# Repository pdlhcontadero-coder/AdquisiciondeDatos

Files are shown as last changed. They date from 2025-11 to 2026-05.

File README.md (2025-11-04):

# ⚙️ Proyecto: Sistema de Monitoreo IoT Aplicado a Cultivos de Lechuga Hidropónica

Este proyecto utiliza la **ESP32** como microcontrolador principal en tres diferentes versiones, con el objetivo de recolectar datos de variables críticas de cultivos hidropónicos, tales como:  
**pH, conductividad eléctrica, temperatura y humedad relativa, temperatura del agua, nivel de agua en los tubos y nivel de agua en el tanque.**

---

<p align="center">
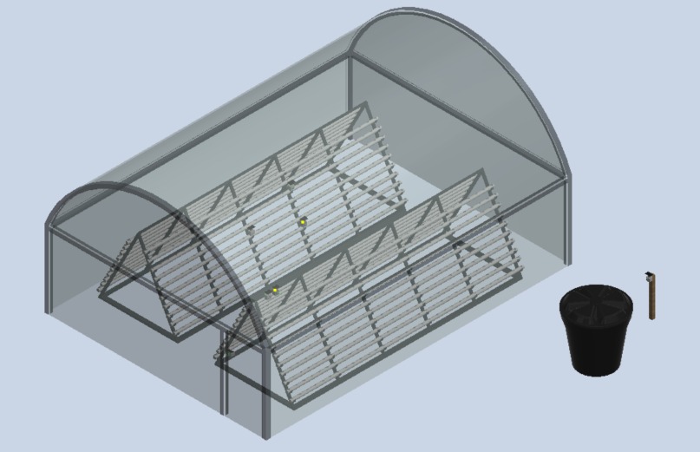
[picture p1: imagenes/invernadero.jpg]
  <br>
  <em>Invernadero - Unidad de Cultivo</em>
</p>

---

## 🧰 Componentes Utilizados

- 1 LilyGo T-SIM-A7670E  
- 3 ESP32-C3 Super Mini Plus  
- 1 ESP32 DevKit V1  
- 1 Sensor de pH con electrodo industrial  
- 1 Sensor de conductividad eléctrica  
- 1 Sensor de temperatura y humedad DHT22  
- 2 Sensores de temperatura DS18B20  
- 4 Sensores de nivel analógicos  
- 1 Sensor de nivel ultrasónico  
- 2 Módulos ADC ADS1115  
- 5 Pantallas OLED 1.3"  
- 5 Módulos de carga TP4056  
- 5 Paneles solares de 5 V  
- 10 Baterías 18650 (2 por cada módulo)  
- 9 Pulsadores (3 por cada módulo que los incluye)  

---

## 🧠 Funcionamiento General

El sistema está conformado por **5 módulos**, de los cuales:
- **4 módulos emisores** se encargan de recolectar los datos de los sensores asignados y enviarlos mediante el protocolo ESPNOW.
- **1 módulo receptor (principal)** recibe toda la información de los emisores y la envía a una **base de datos** para su almacenamiento y análisis.

---

## 🖼️ Diagramas e Imágenes de los Módulos

### 📊 Diagramas de Conexión

<p align="center">
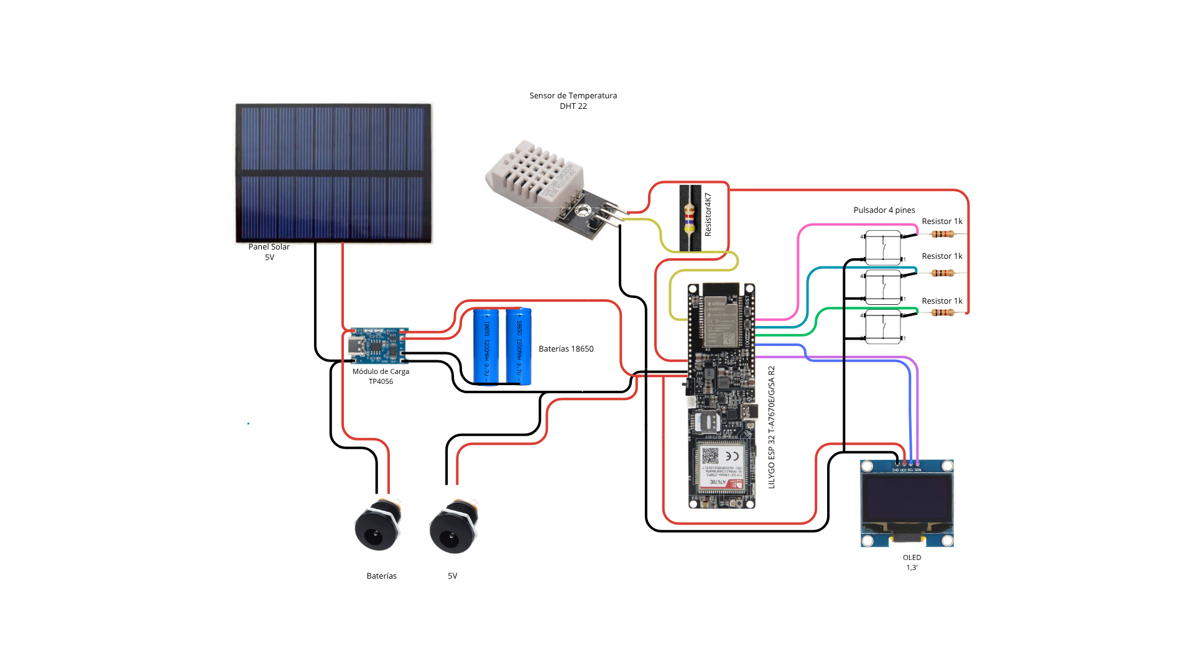
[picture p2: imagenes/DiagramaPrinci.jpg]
  <br>
  <em>Diagrama de conexión - Módulo principal</em>
</p>

<p align="center">
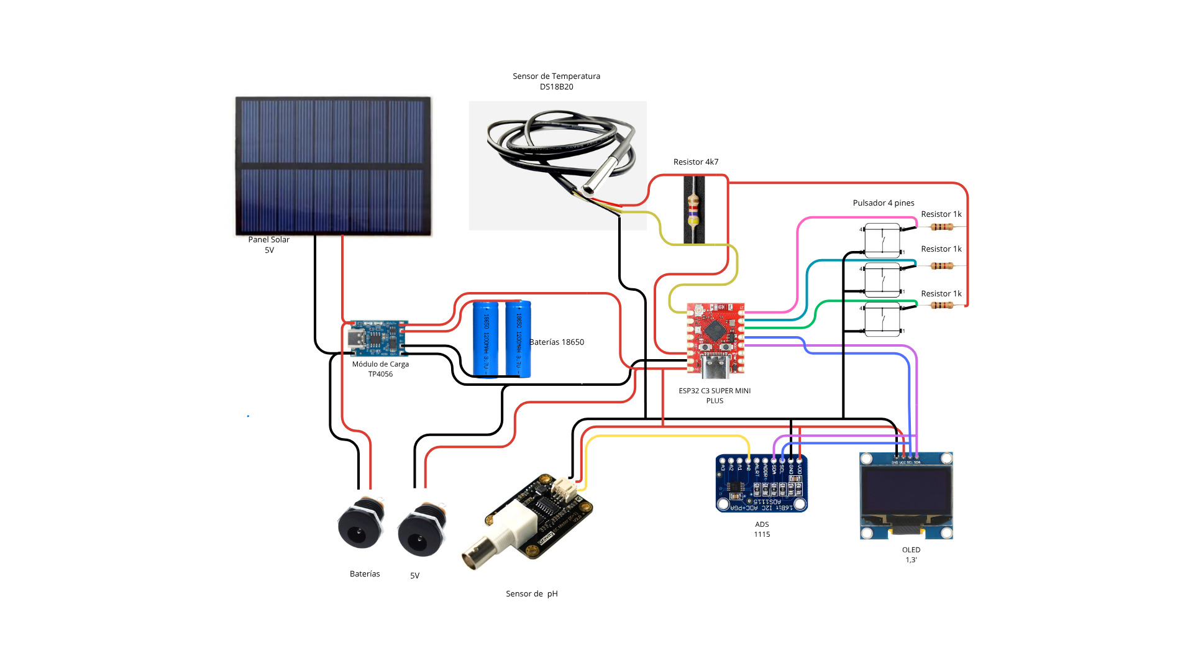
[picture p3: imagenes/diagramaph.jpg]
  <br>
  <em>Diagrama de conexión - Módulo pH</em>
</p>

<p align="center">
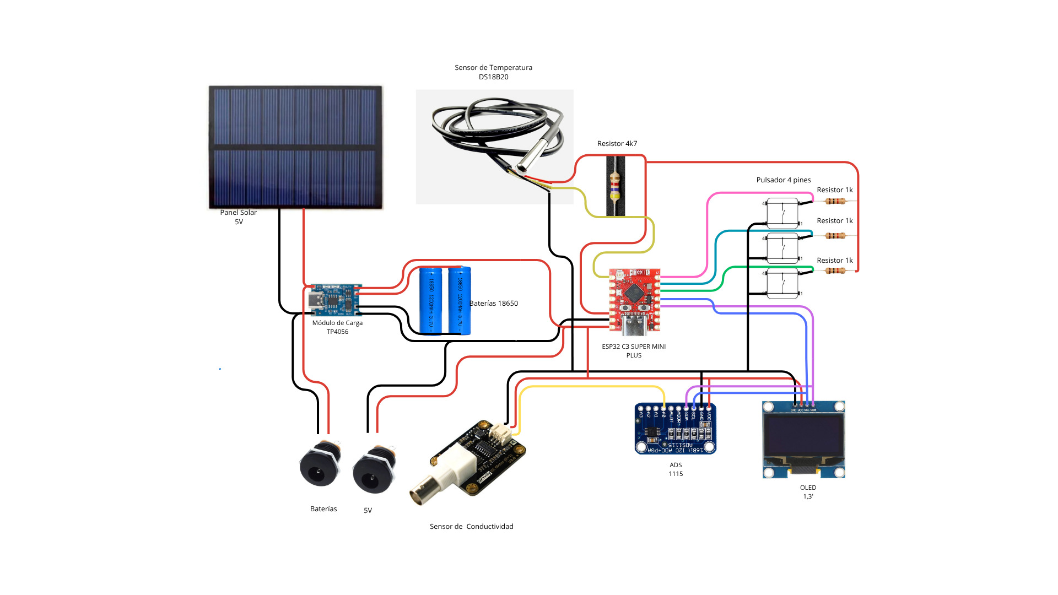
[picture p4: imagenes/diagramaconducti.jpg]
  <br>
  <em>Diagrama de conexión - Módulo conductividad</em>
</p>

<p align="center">
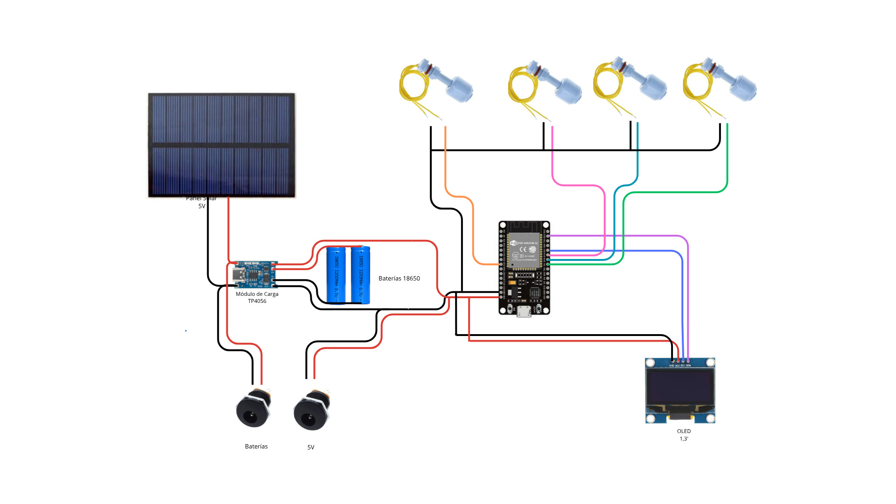
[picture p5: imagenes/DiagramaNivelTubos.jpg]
  <br>
  <em>Diagrama de conexión - Módulo nivel de agua en tubos</em>
</p>

<p align="center">
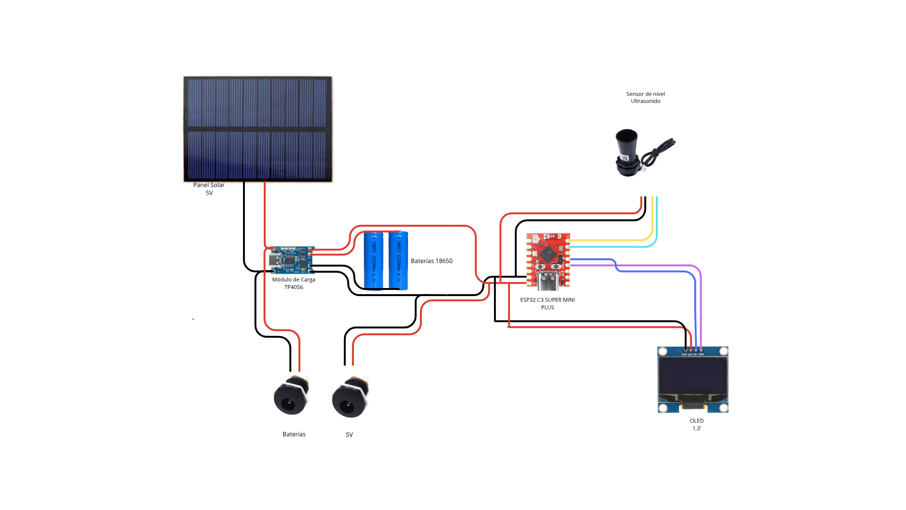
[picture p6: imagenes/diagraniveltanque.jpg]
  <br>
  <em>Diagrama de conexión - Módulo nivel de agua en tanque</em>
</p>

---

### 🧩 Montaje Real de los Módulos

<p align="center">
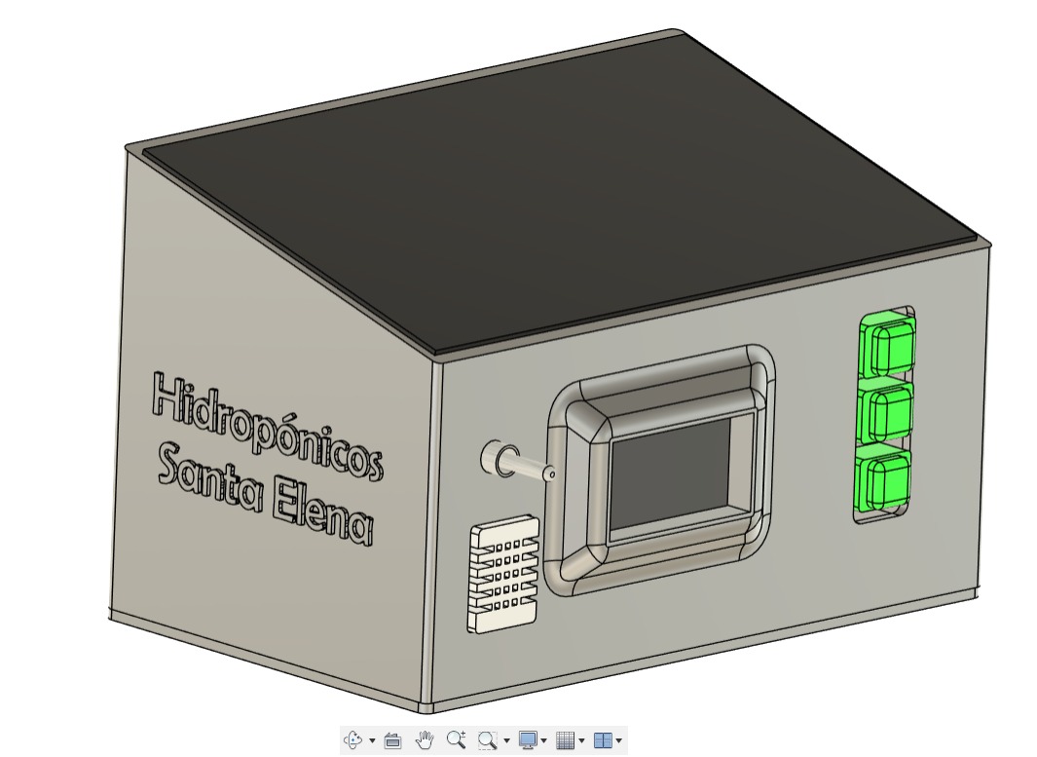
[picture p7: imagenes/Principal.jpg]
  <br>
  <em>Montaje del módulo principal</em>
</p>

<p align="center">
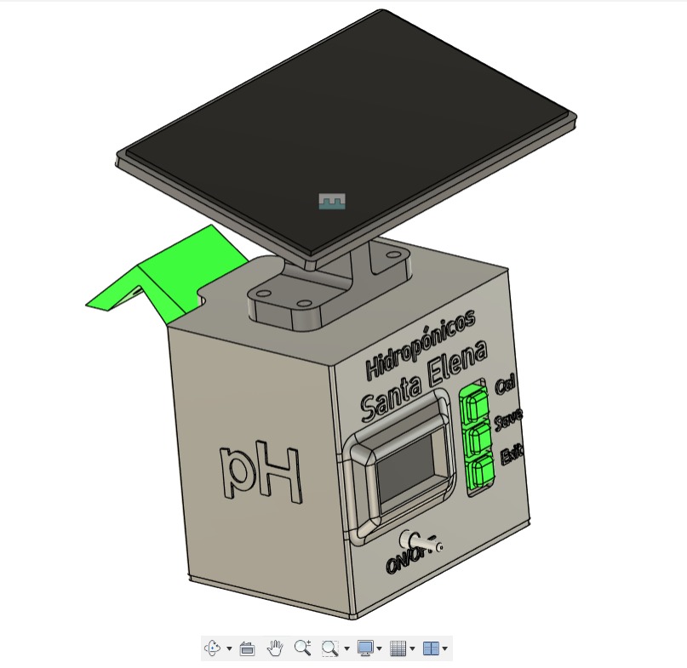
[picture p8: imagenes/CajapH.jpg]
  <br>
  <em>Montaje del módulo pH</em>
</p>

<p align="center">
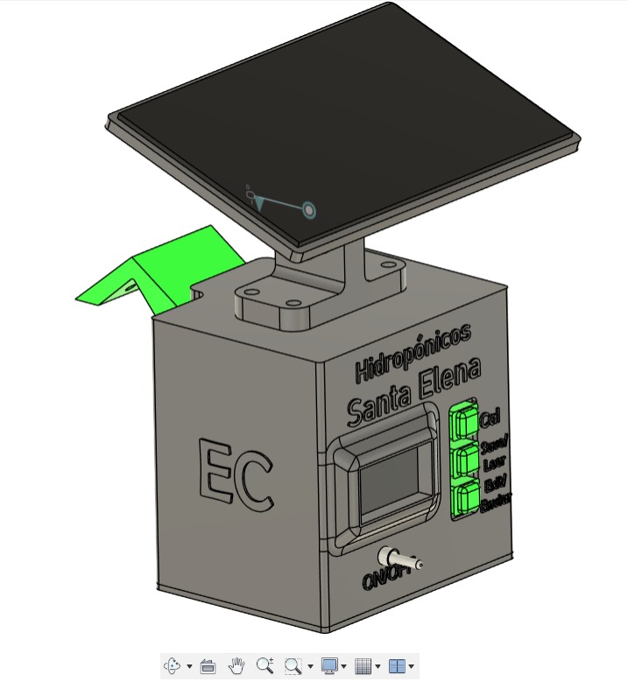
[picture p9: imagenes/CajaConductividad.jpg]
  <br>
  <em>Montaje del módulo conductividad</em>
</p>

<p align="center">
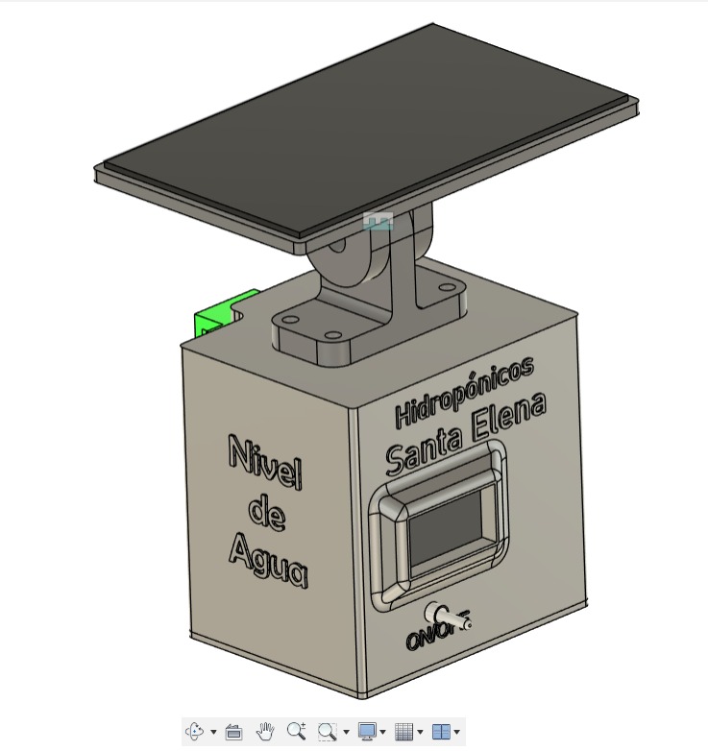
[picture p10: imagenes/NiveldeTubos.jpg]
  <br>
  <em>Montaje del módulo nivel de agua en tubos</em>
</p>

<p align="center">
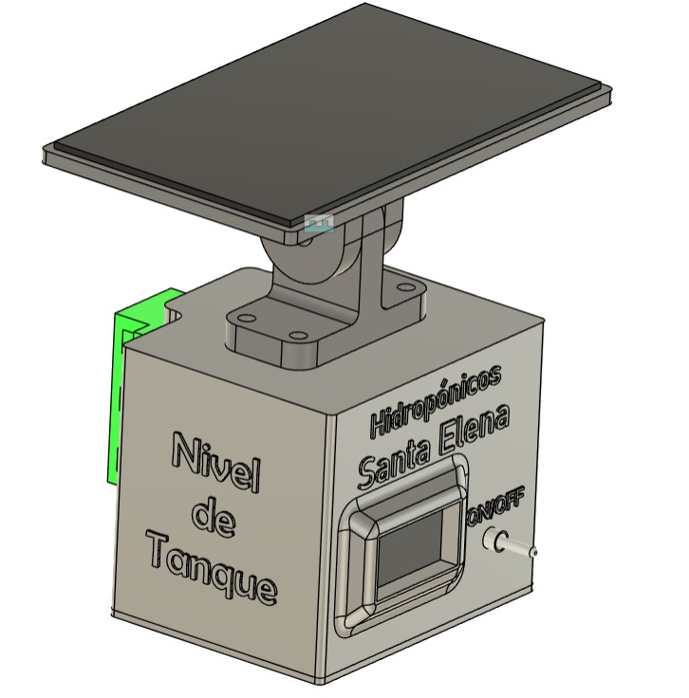
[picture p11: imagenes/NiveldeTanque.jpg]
  <br>
  <em>Montaje del módulo nivel de agua en tanque</em>
</p>

---
###  🔗 Repositorio relacionado

📦 [Repositorio de base de datos y página web](https://github.com/pdlhcontadero-coder/PMLHC)

---
## 👥 Autores

- **Alejandro Díaz Igua**  
- **David Eraso García**  
- **Ana Sofía Muñoz Villota**  
- **Ivette Camila Yepez Morán**

---

📍 *Proyecto académico.*

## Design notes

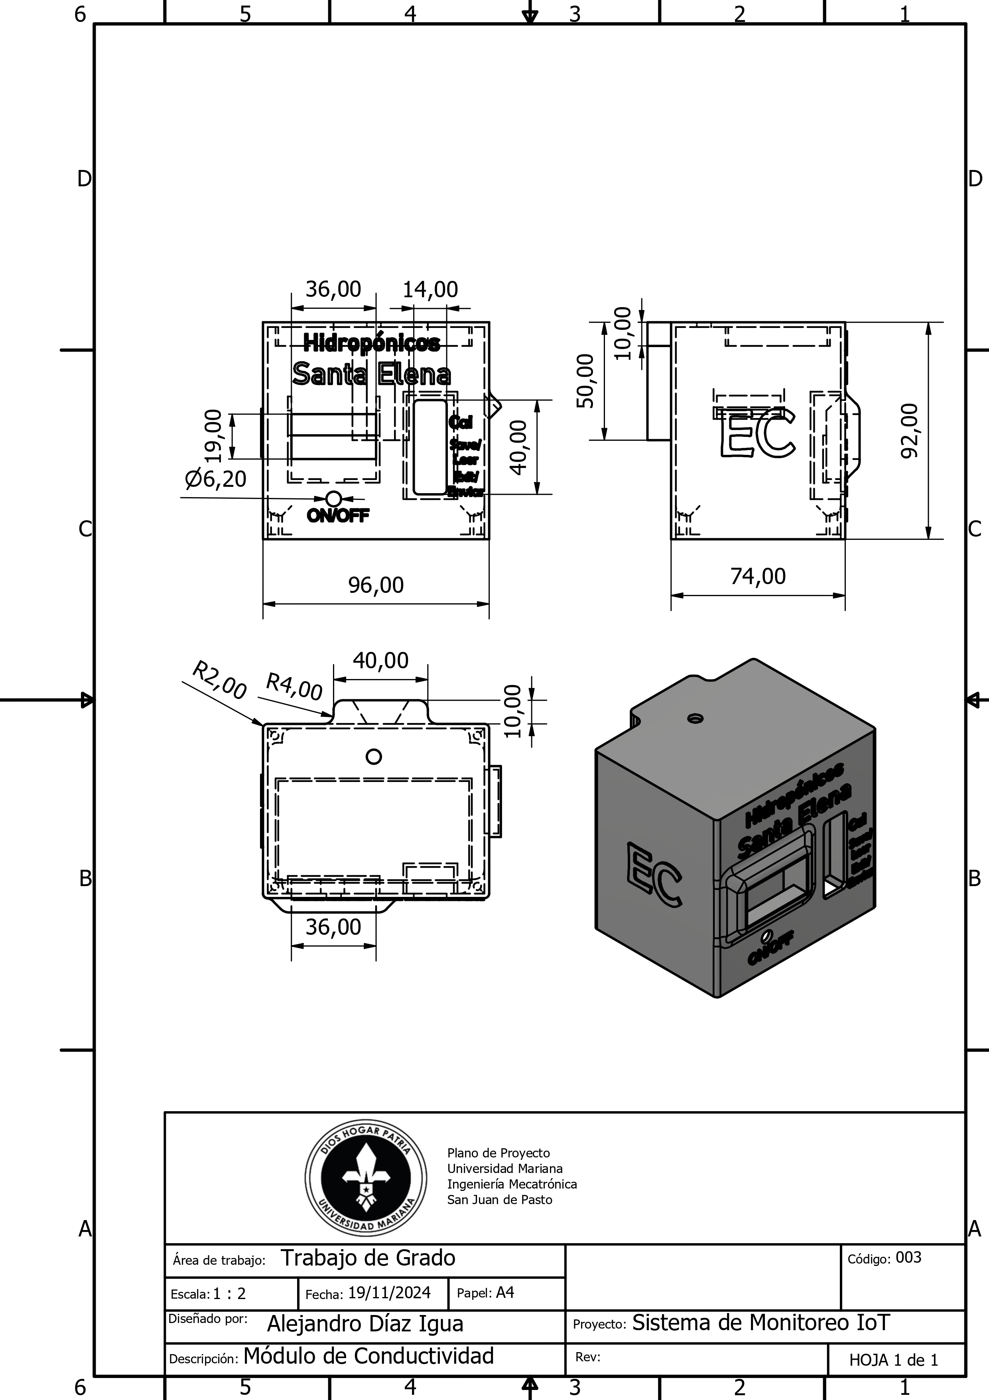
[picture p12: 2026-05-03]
Diseño 3D - Inventor/Planos Finales Sistema de Monitoreo/Planos en imagen/003 Plano 3 - Módulo de Conductividad (Caja).jpg

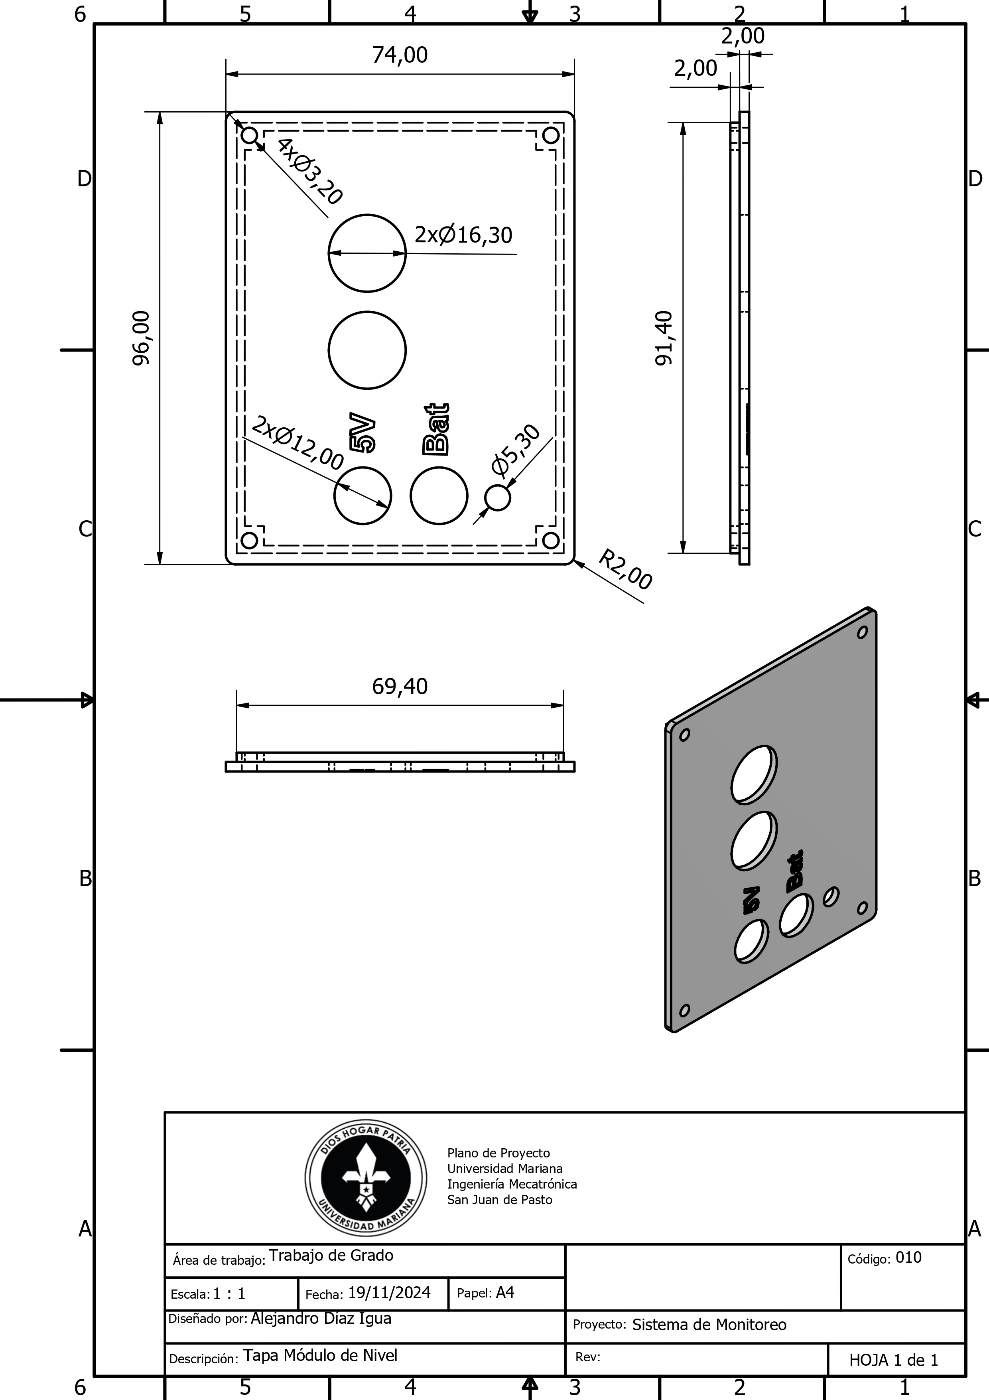
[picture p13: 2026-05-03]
Diseño 3D - Inventor/Planos Finales Sistema de Monitoreo/Planos en imagen/010 Plano 10 - Módulo de Nivel de Agua (Tapa).jpg

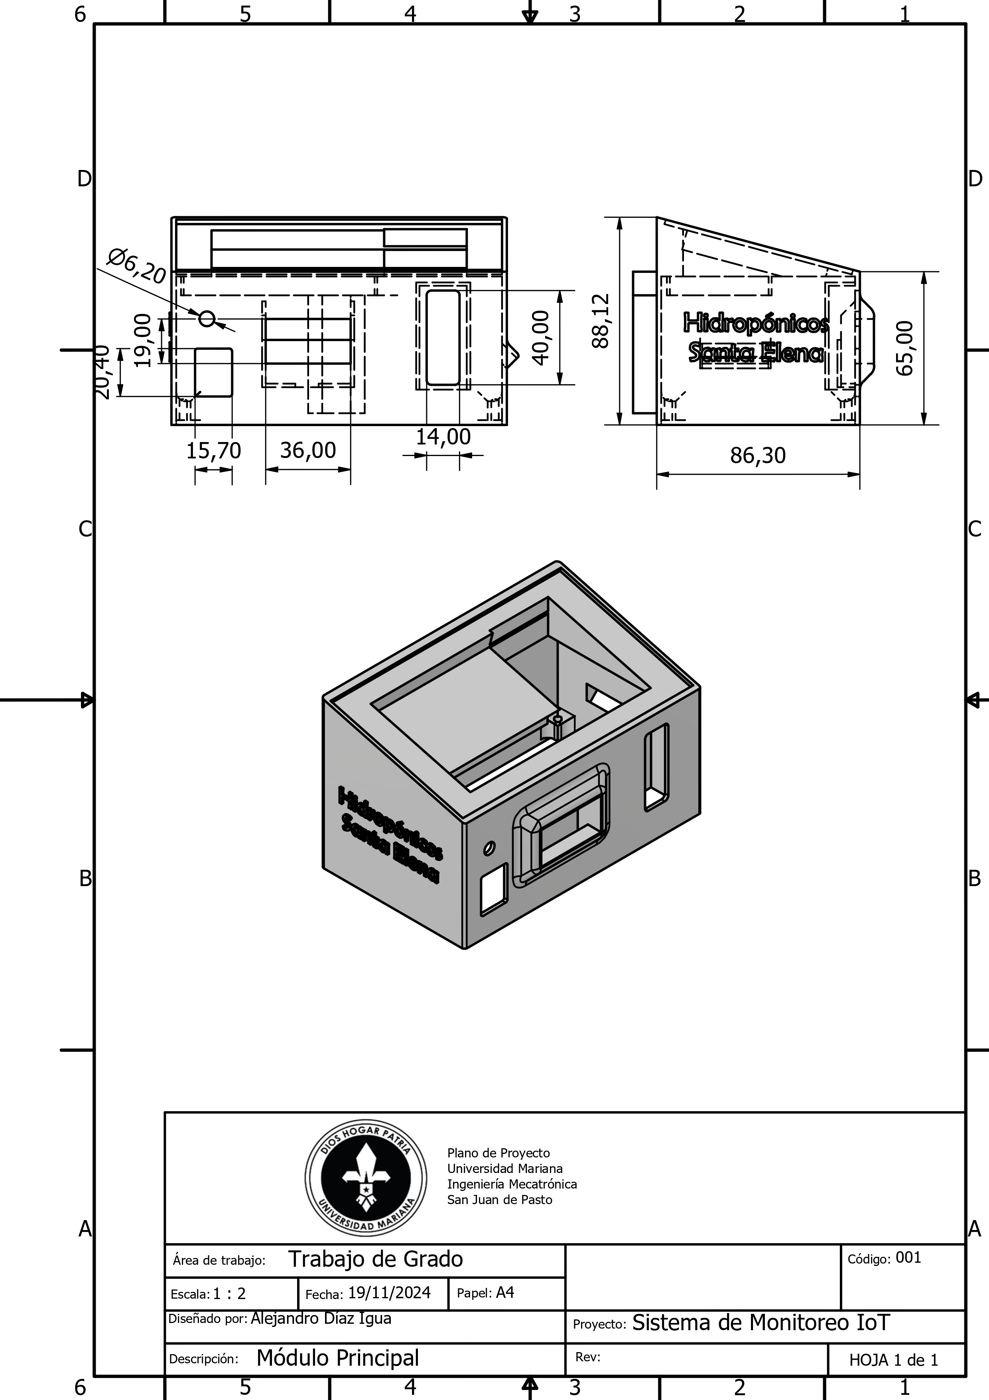
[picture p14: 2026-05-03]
Diseño 3D - Inventor/Planos Finales Sistema de Monitoreo/Planos en imagen/001 Plano 1 - Módulo Principal (Caja).jpg

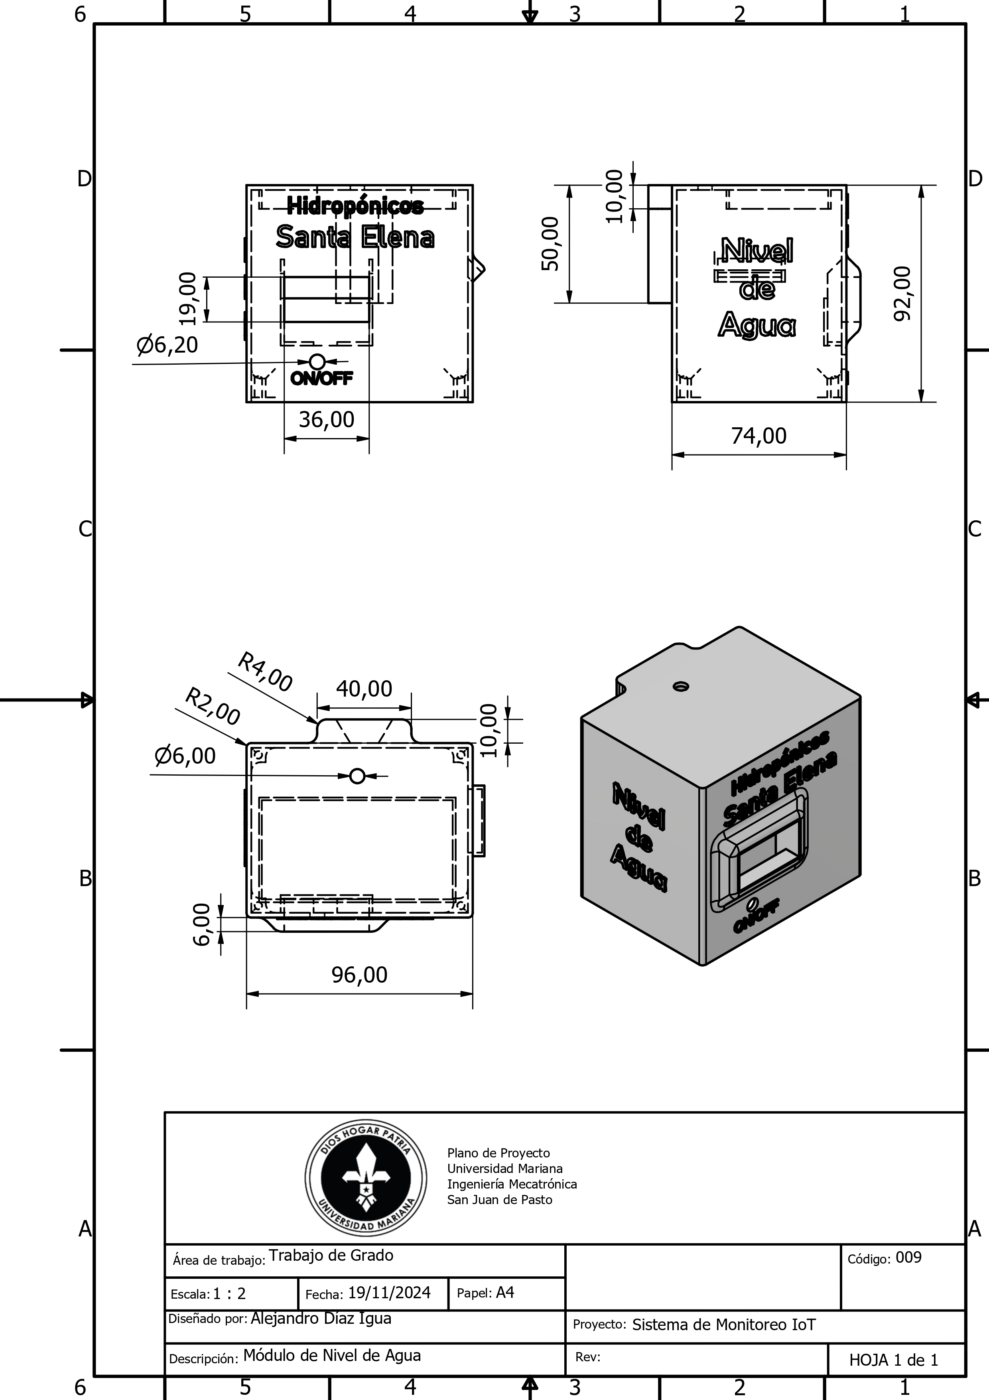
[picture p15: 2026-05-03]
Diseño 3D - Inventor/Planos Finales Sistema de Monitoreo/Planos en imagen/009 Plano 9 - Módulo de Nivel de Agua (Caja).jpg

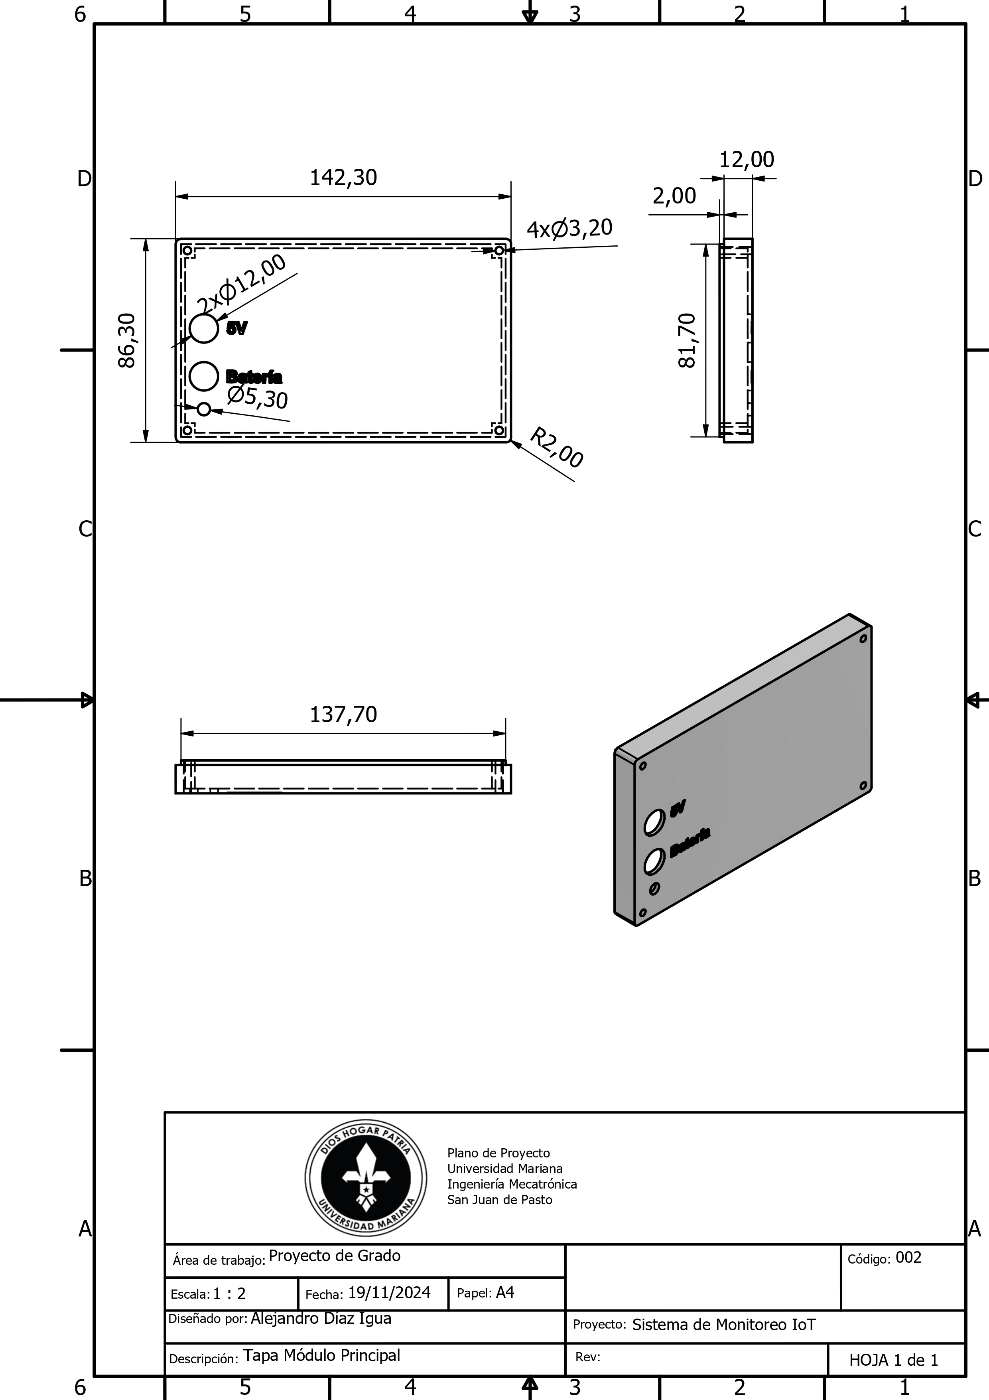
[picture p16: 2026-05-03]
Diseño 3D - Inventor/Planos Finales Sistema de Monitoreo/Planos en imagen/002 Plano 2 - Módulo Principal (Tapa).jpg

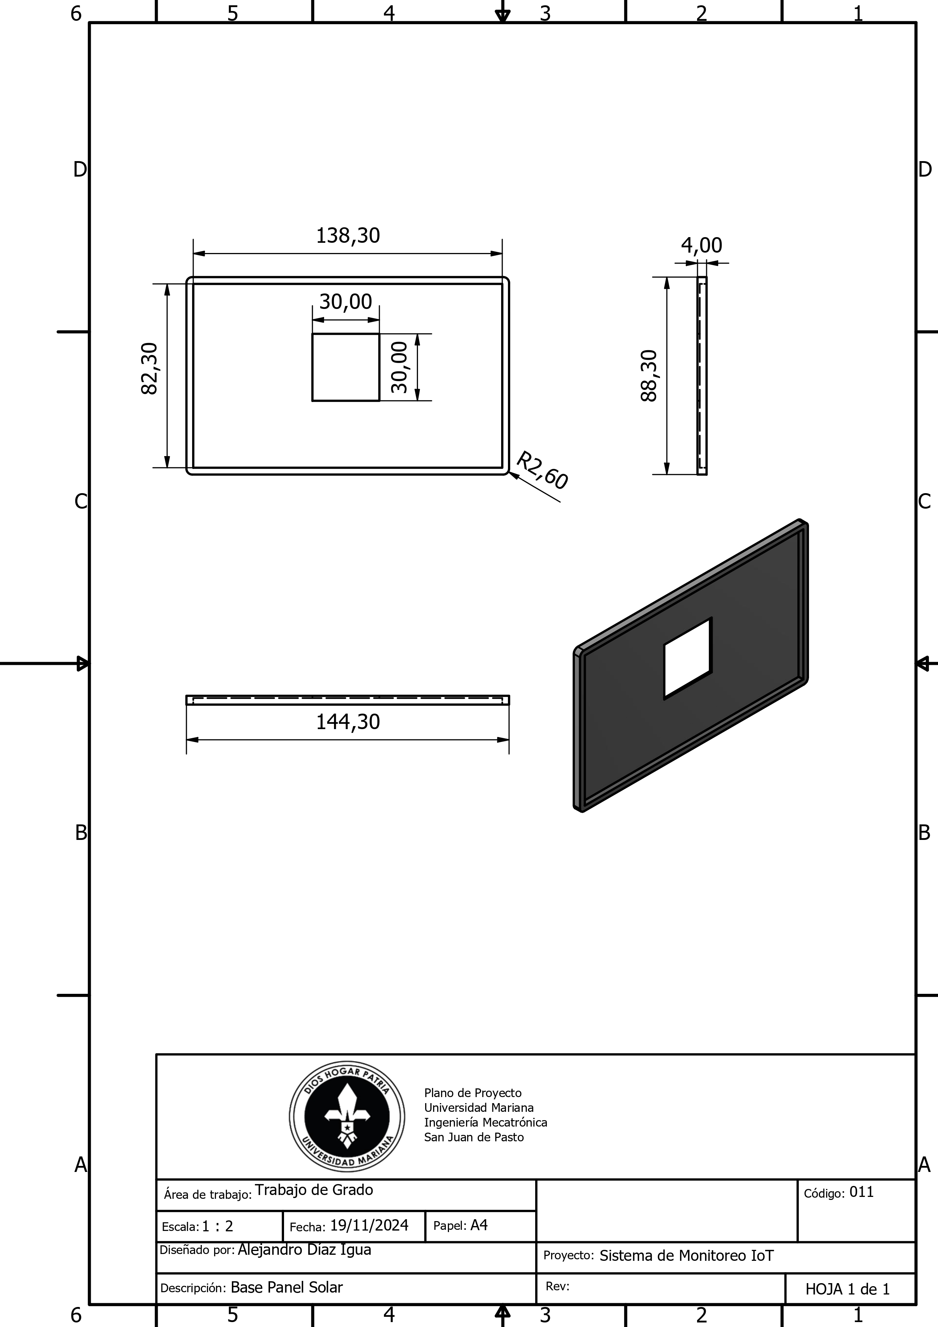
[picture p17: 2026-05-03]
Diseño 3D - Inventor/Planos Finales Sistema de Monitoreo/Planos en imagen/011 Plano 11 - Base Panel Solar.jpg

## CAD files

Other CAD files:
Diseño 3D - Inventor/Invernadero/Ensamble/Ensamblaje1.iam
Diseño 3D - Inventor/Invernadero/Ensamble/OldVersions/Ensamblaje1.0007.iam
Diseño 3D - Inventor/Invernadero/Piezas/Caja.ipt
Diseño 3D - Inventor/Invernadero/Piezas/Invernadero.ipt
Diseño 3D - Inventor/Invernadero/Piezas/OldVersions/Invernadero.0002.ipt
Diseño 3D - Inventor/Invernadero/Piezas/OldVersions/TapaTanque.0001.ipt
Diseño 3D - Inventor/Invernadero/Piezas/OldVersions/Torre.0004.ipt
Diseño 3D - Inventor/Invernadero/Piezas/OldVersions/Tubo.0001.ipt
Diseño 3D - Inventor/Invernadero/Piezas/Soporte.ipt
Diseño 3D - Inventor/Invernadero/Piezas/Tanque.ipt
Diseño 3D - Inventor/Invernadero/Piezas/TapaTanque.ipt
Diseño 3D - Inventor/Invernadero/Piezas/Torre.ipt
Diseño 3D - Inventor/Invernadero/Piezas/Tubo.ipt
Diseño 3D - Inventor/Módulo EC/Boton.ipt
Diseño 3D - Inventor/Módulo EC/Caja EC Final.iam
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

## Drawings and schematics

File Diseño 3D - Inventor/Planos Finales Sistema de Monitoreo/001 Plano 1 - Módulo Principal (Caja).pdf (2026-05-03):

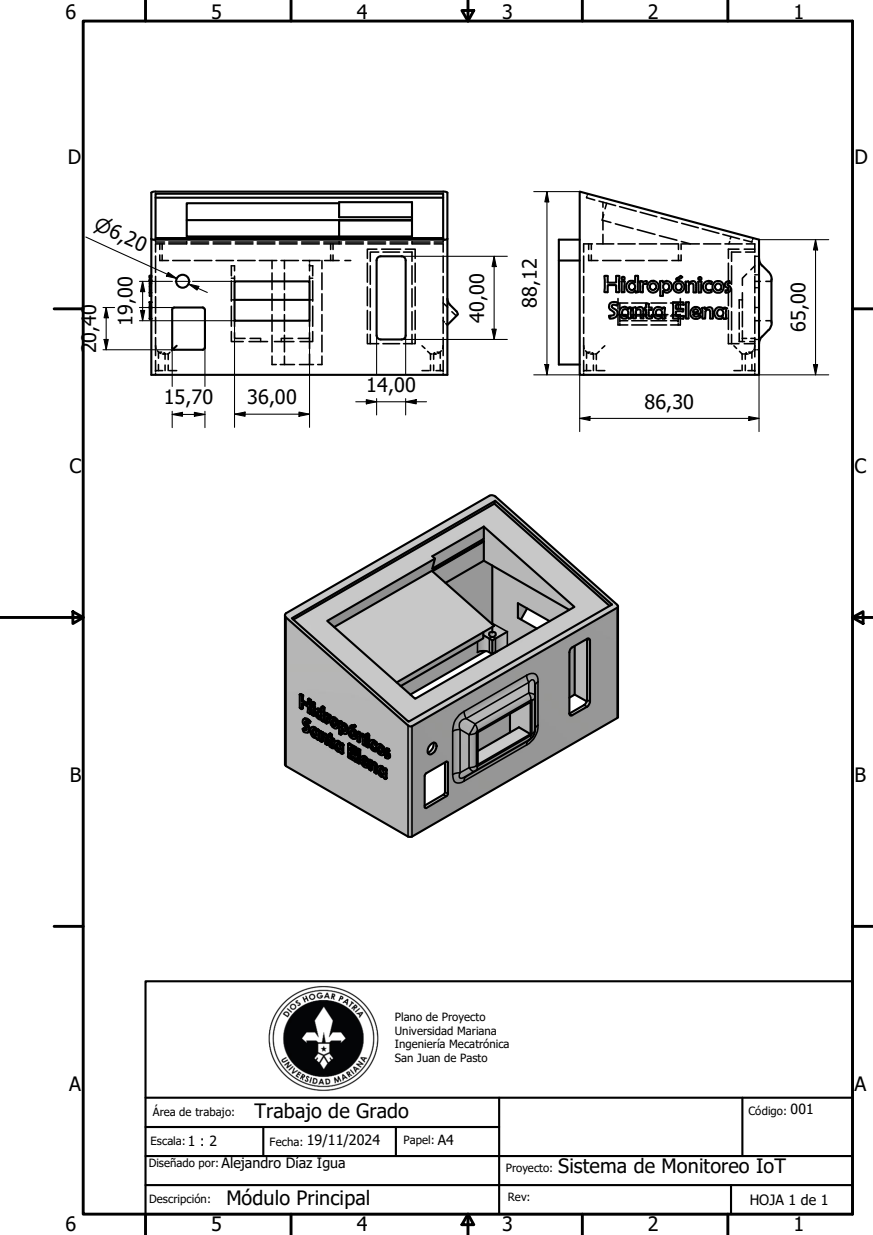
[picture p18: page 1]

Plano de Proyecto
Universidad Mariana
Ingeniería Mecatrónica
San Juan de Pasto

Área de trabajo: Trabajo de Grado | | Código: 001

Escala: 1 : 2 | Fecha: 19/11/2024 | Papel: A4
Diseñado por: Alejandro Díaz Igua | Proyecto: Sistema de Monitoreo IoT

Descripción: Módulo Principal | Rev: | HOJA 1 de 1

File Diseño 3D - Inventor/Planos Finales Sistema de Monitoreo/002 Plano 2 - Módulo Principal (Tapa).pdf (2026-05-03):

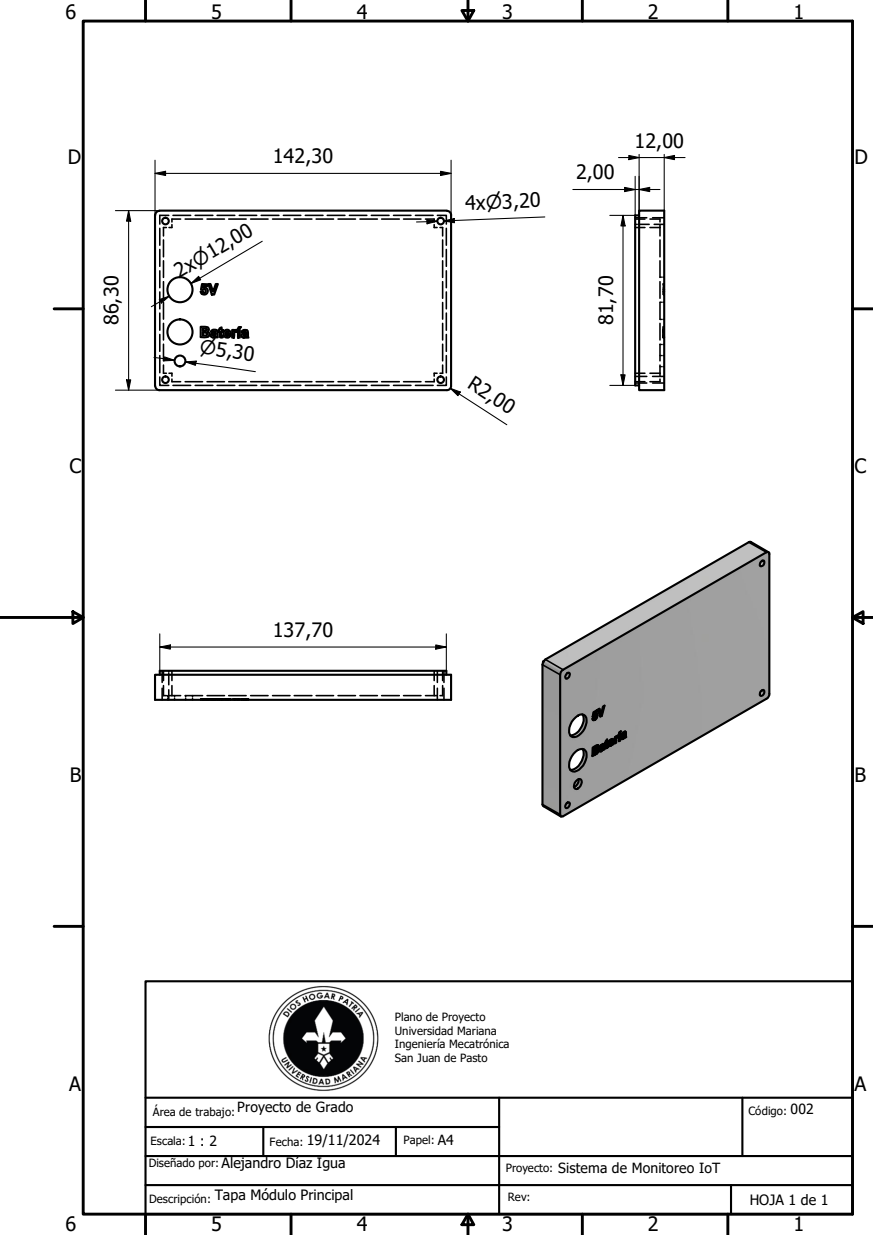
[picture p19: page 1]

Plano de Proyecto
Universidad Mariana
Ingeniería Mecatrónica
San Juan de Pasto

Área de trabajo: Proyecto de Grado | | Código: 002

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

Descripción: Tapa Módulo Principal | Rev: | HOJA 1 de 1

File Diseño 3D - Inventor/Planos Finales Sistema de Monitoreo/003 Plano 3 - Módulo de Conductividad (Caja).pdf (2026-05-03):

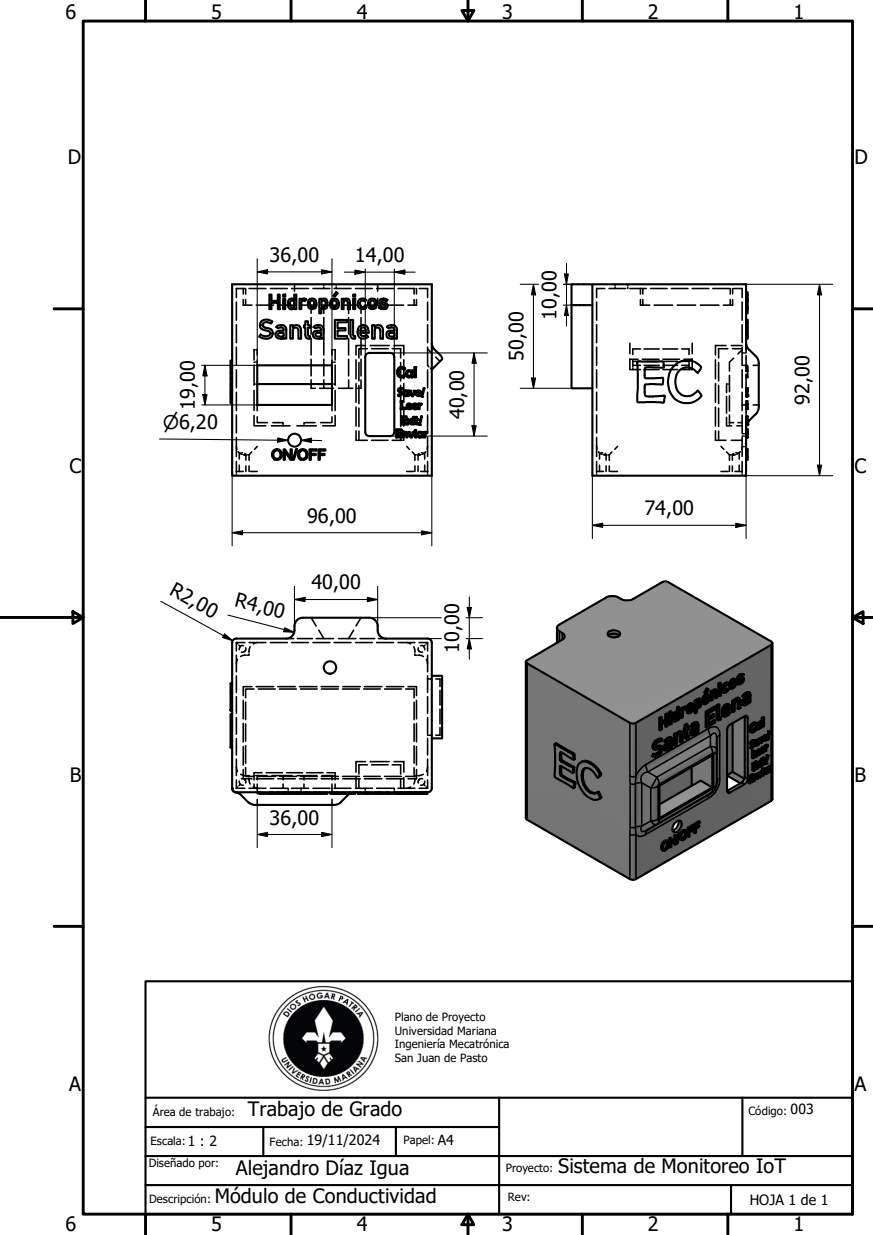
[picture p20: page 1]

Plano de Proyecto
Universidad Mariana
Ingeniería Mecatrónica
San Juan de Pasto

Área de trabajo: Trabajo de Grado | | Código: 003

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

Descripción: Módulo de Conductividad | Rev: | HOJA 1 de 1

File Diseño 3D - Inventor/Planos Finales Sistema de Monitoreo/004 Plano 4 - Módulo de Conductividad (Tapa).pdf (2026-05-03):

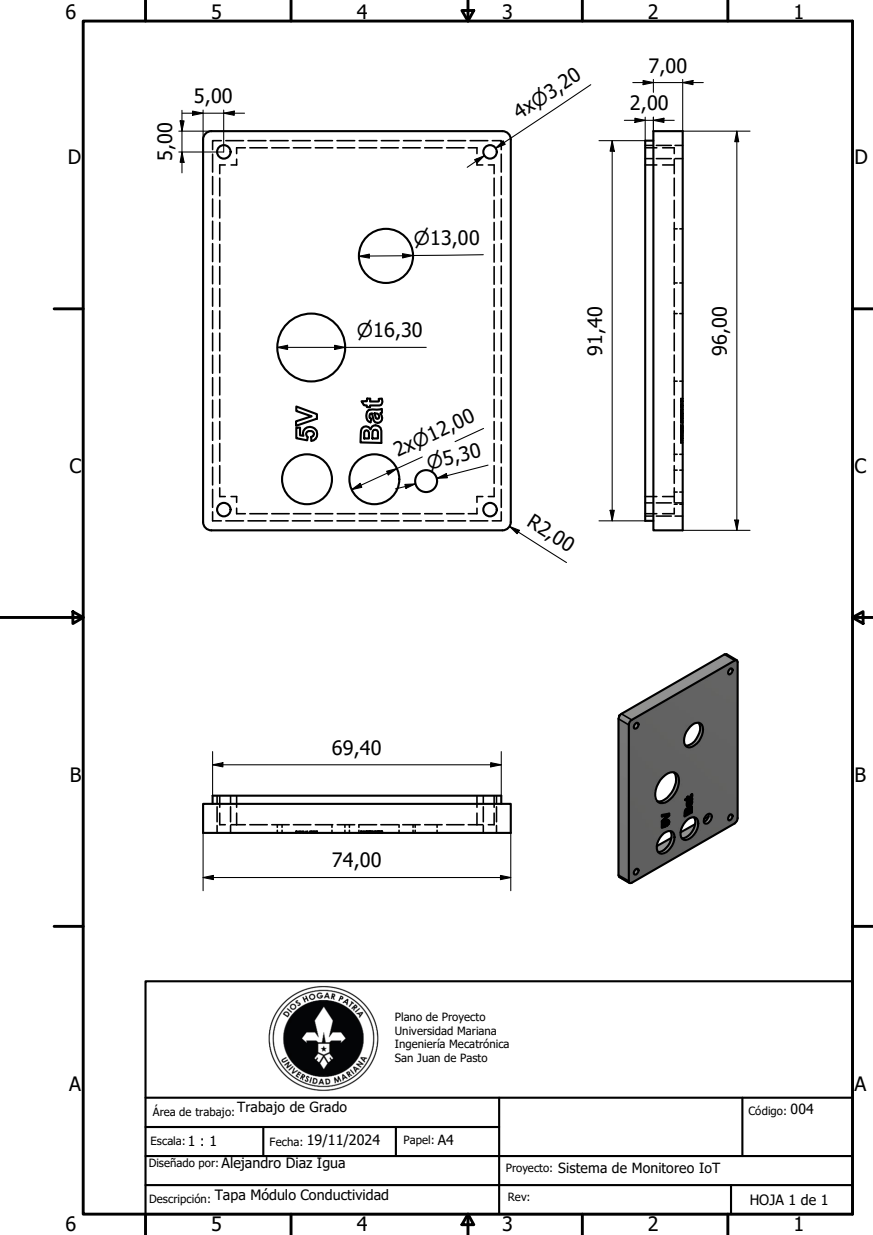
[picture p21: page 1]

Plano de Proyecto
Universidad Mariana
Ingeniería Mecatrónica
San Juan de Pasto

Área de trabajo: Trabajo de Grado | | Código: 004

Escala: 1 : 1 | Fecha: 19/11/2024 | Papel: A4
Diseñado por: Alejandro Diaz Igua | Proyecto: Sistema de Monitoreo IoT

Descripción: Tapa Módulo Conductividad | Rev: | HOJA 1 de 1

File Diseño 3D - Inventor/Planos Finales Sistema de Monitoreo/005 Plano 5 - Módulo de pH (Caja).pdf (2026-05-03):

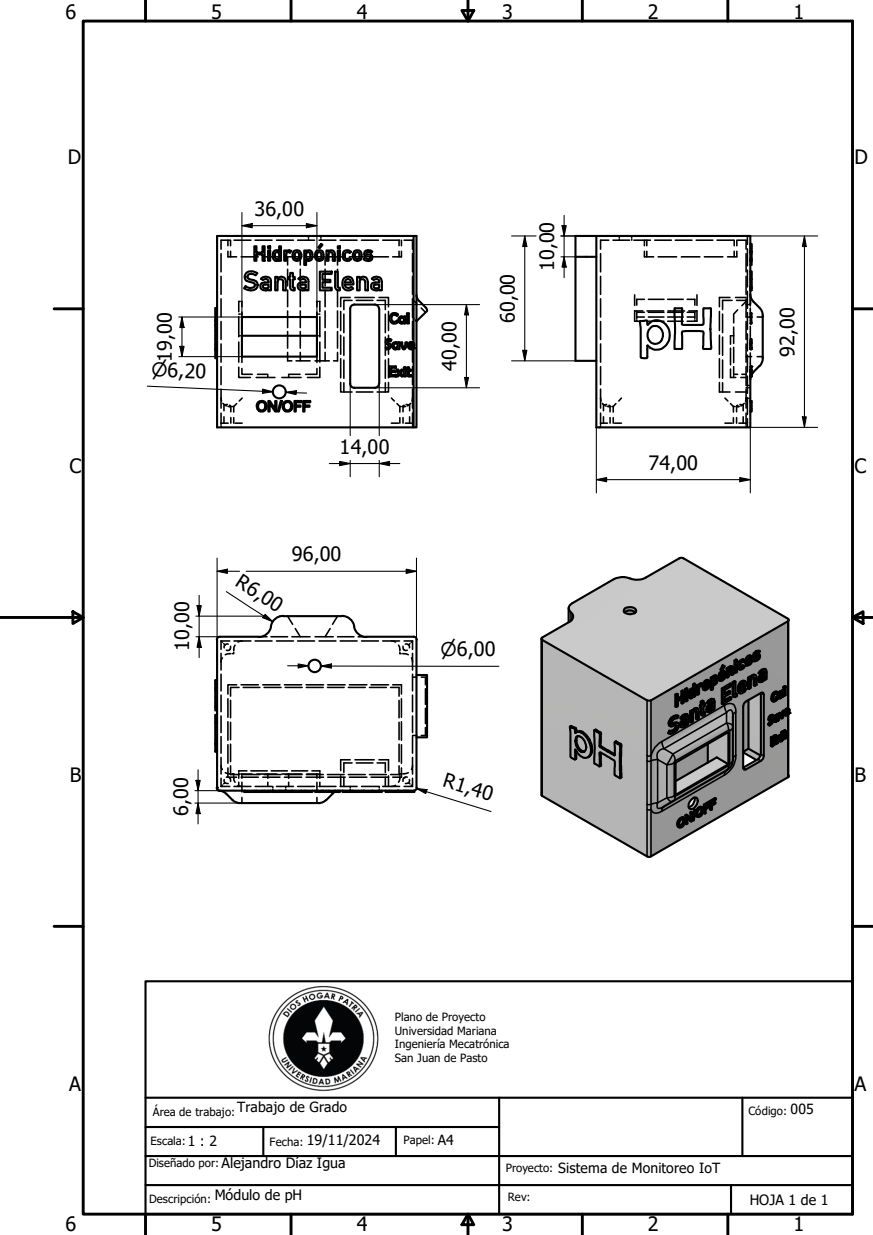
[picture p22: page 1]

Plano de Proyecto
Universidad Mariana
Ingeniería Mecatrónica
San Juan de Pasto

Área de trabajo: Trabajo de Grado | | Código: 005

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

Descripción: Módulo de pH | Rev: | HOJA 1 de 1

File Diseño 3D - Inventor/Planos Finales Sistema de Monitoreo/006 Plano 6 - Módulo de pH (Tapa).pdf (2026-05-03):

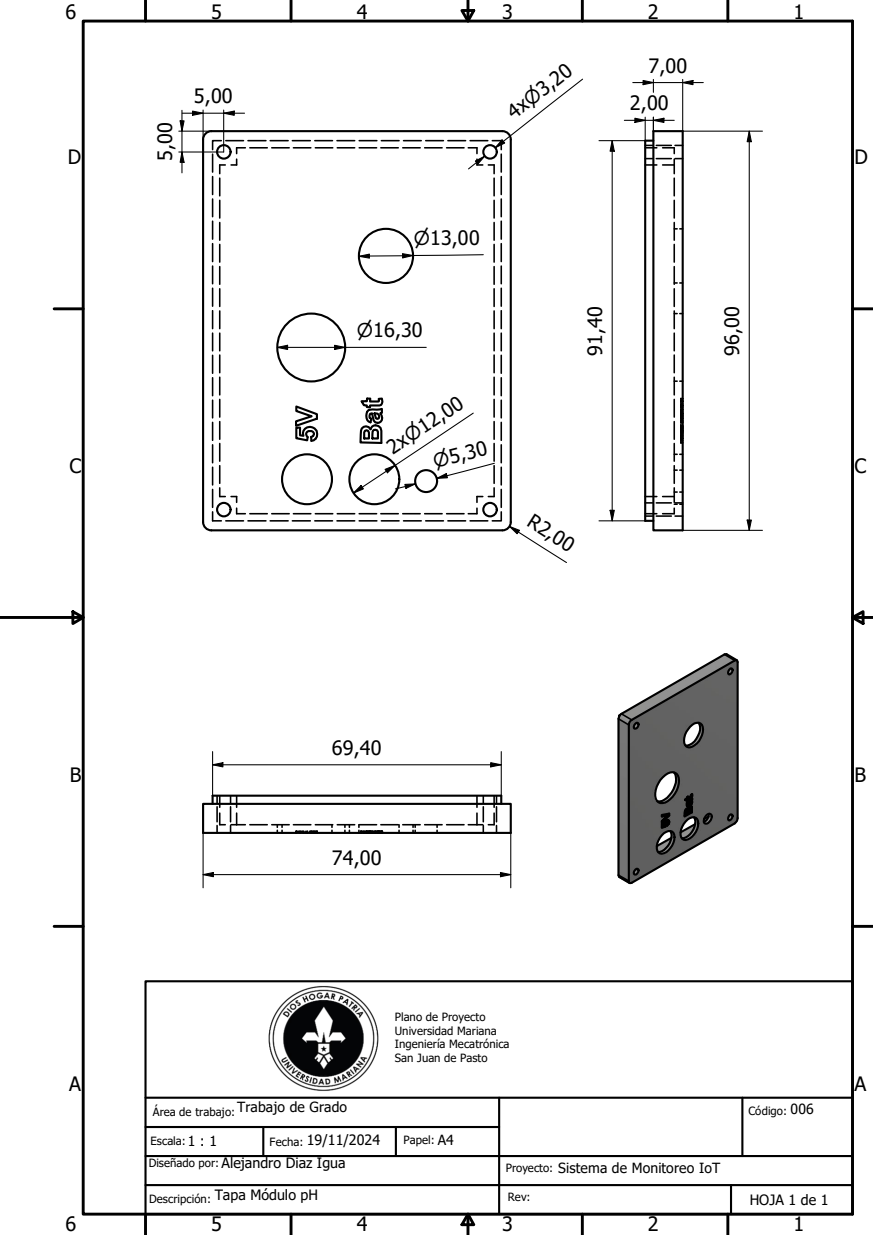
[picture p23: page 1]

Plano de Proyecto
Universidad Mariana
Ingeniería Mecatrónica
San Juan de Pasto

Área de trabajo: Trabajo de Grado | | Código: 006

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

Descripción: Tapa Módulo pH | Rev: | HOJA 1 de 1

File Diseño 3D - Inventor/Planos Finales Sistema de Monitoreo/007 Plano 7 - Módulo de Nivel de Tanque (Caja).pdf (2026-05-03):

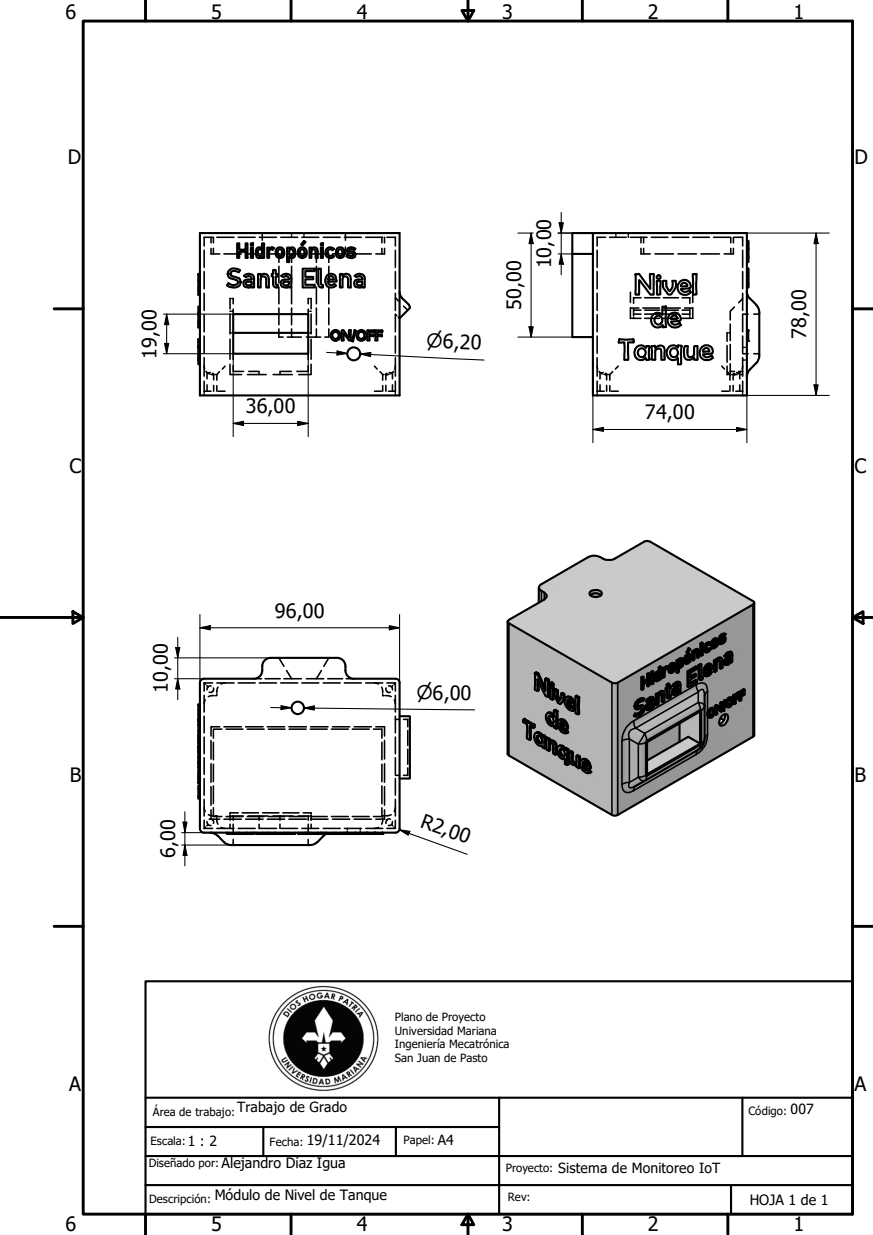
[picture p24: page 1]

Plano de Proyecto
Universidad Mariana
Ingeniería Mecatrónica
San Juan de Pasto

Área de trabajo: Trabajo de Grado | | Código: 007

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

Descripción: Módulo de Nivel de Tanque | Rev: | HOJA 1 de 1

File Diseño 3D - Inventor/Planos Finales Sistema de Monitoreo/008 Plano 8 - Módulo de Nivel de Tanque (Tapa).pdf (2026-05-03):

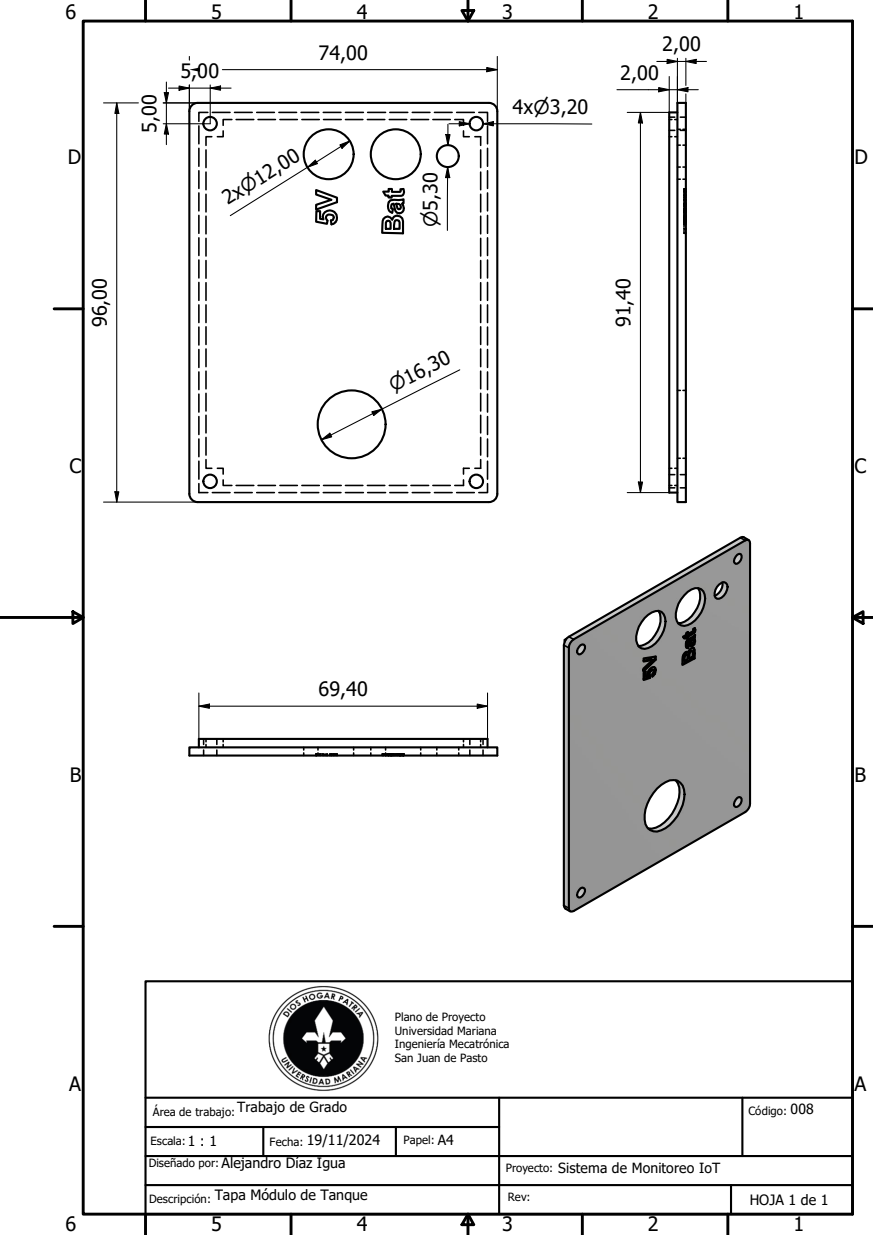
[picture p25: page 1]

Plano de Proyecto
Universidad Mariana
Ingeniería Mecatrónica
San Juan de Pasto

Área de trabajo: Trabajo de Grado | | Código: 008

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

Descripción: Tapa Módulo de Tanque | Rev: | HOJA 1 de 1

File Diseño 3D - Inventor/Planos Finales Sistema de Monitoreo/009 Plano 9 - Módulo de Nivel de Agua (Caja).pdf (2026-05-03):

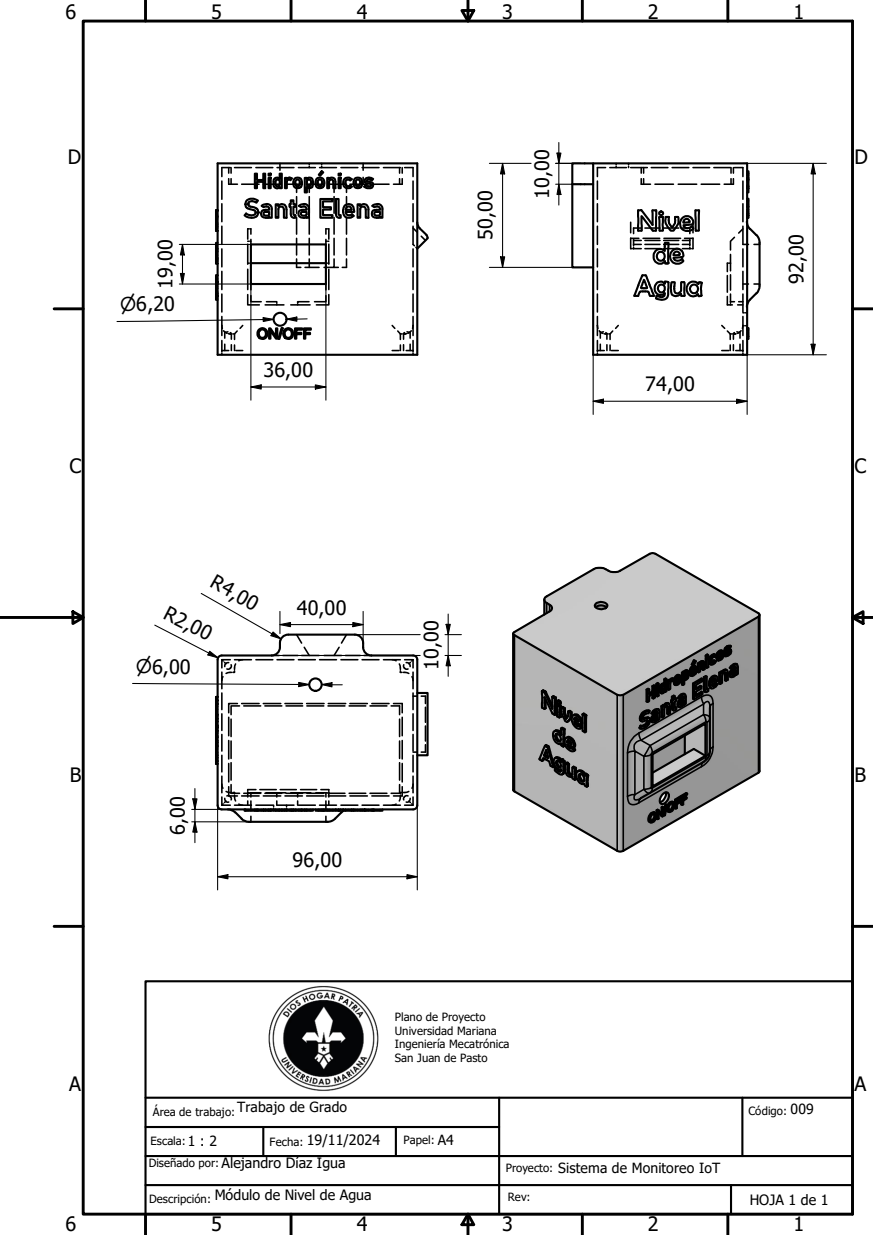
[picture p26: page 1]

Plano de Proyecto
Universidad Mariana
Ingeniería Mecatrónica
San Juan de Pasto

Área de trabajo: Trabajo de Grado | | Código: 009

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

Descripción: Módulo de Nivel de Agua | Rev: | HOJA 1 de 1

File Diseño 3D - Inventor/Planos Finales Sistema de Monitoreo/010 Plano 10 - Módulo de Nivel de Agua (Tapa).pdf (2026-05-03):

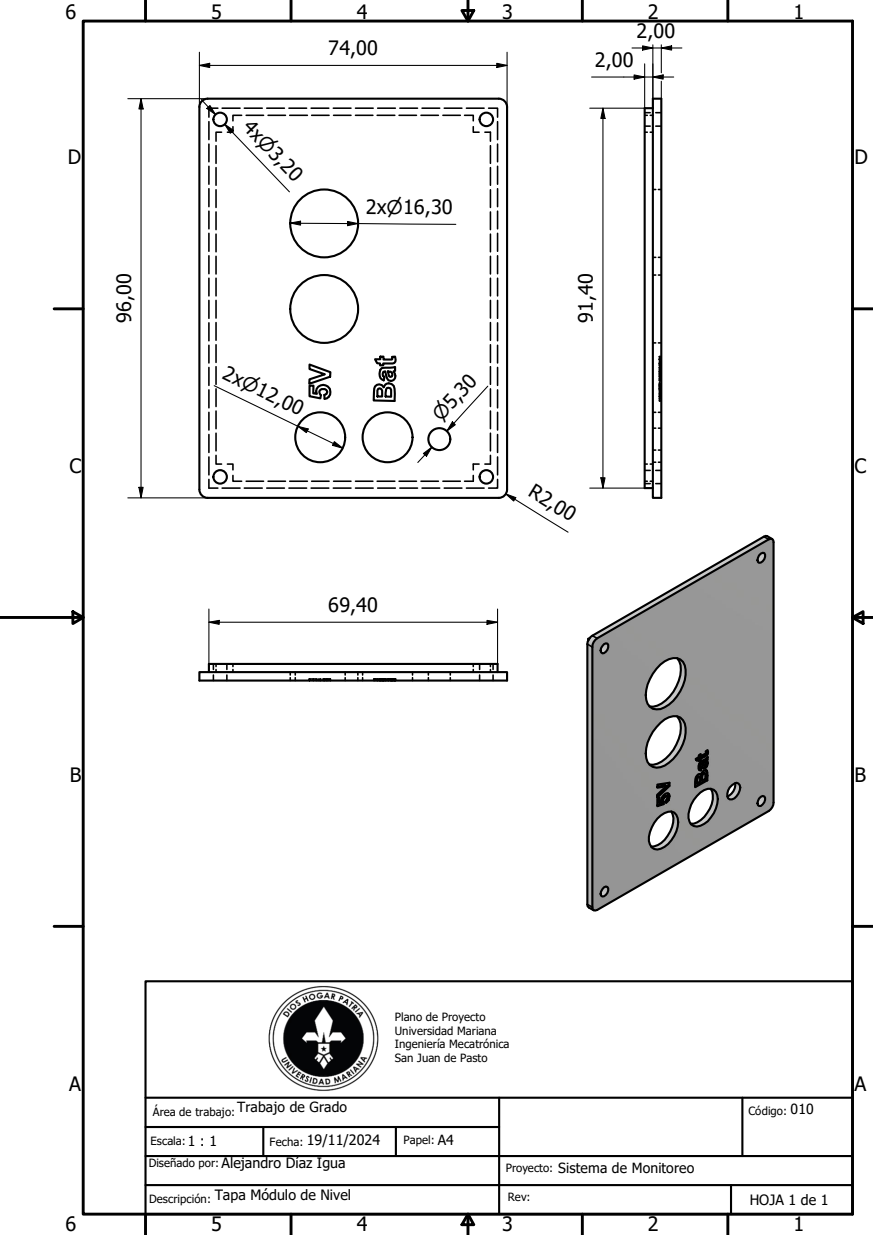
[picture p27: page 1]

Plano de Proyecto
Universidad Mariana
Ingeniería Mecatrónica
San Juan de Pasto

Área de trabajo: Trabajo de Grado | | Código: 010

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

Descripción: Tapa Módulo de Nivel | Rev: | HOJA 1 de 1

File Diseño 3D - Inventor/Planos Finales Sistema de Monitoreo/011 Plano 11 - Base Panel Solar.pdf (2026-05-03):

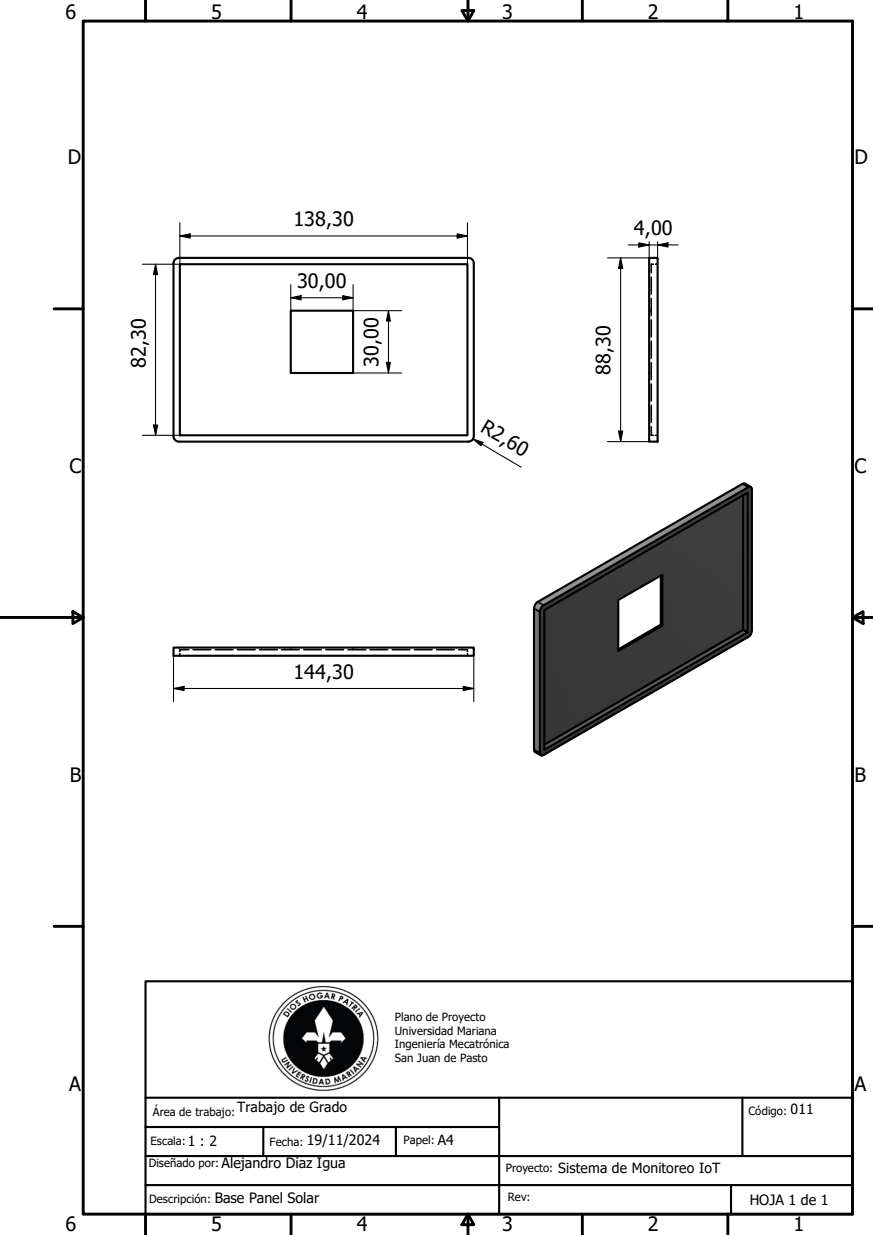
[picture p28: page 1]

Plano de Proyecto
Universidad Mariana
Ingeniería Mecatrónica
San Juan de Pasto

Área de trabajo: Trabajo de Grado | | Código: 011

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

Descripción: Base Panel Solar | Rev: | HOJA 1 de 1

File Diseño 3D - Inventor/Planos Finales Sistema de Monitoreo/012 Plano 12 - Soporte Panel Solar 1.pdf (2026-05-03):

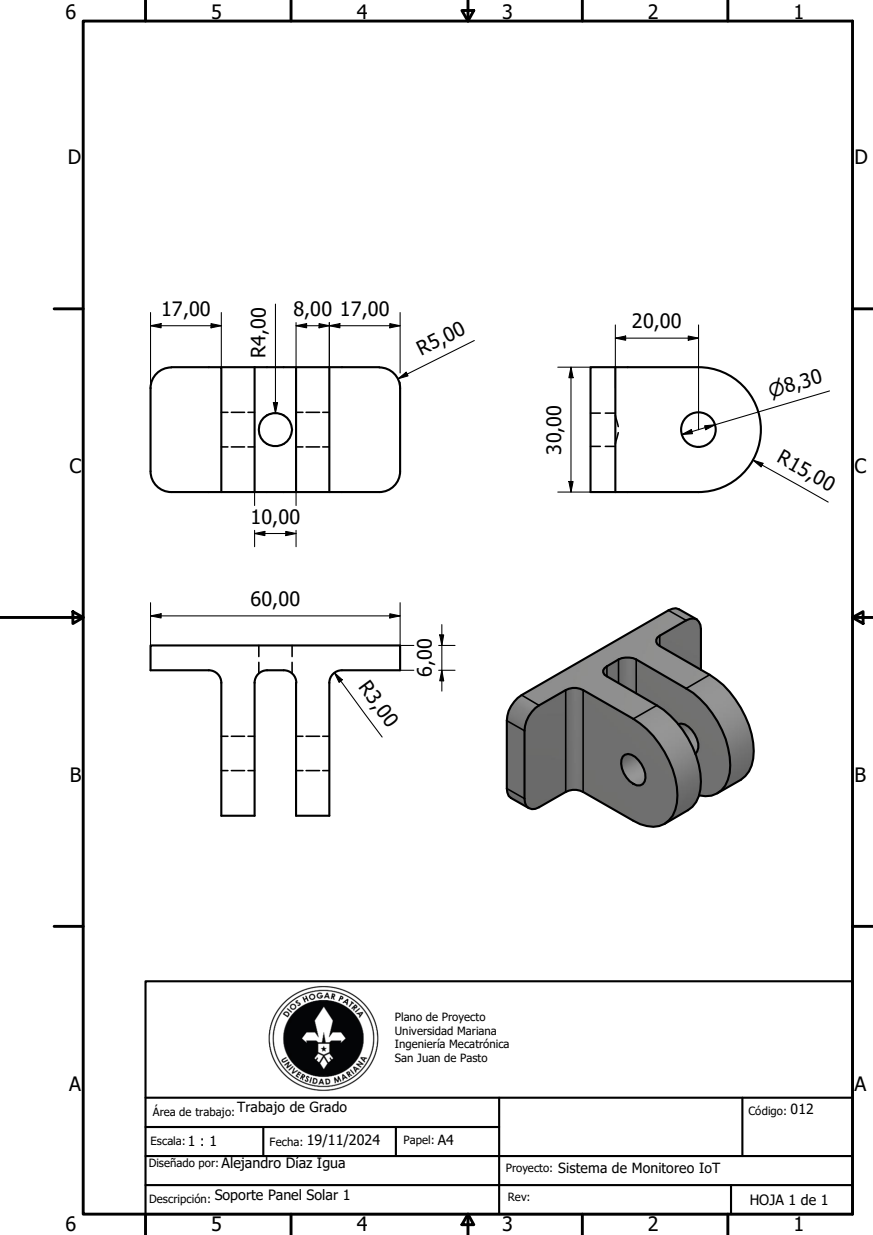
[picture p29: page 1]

Plano de Proyecto
Universidad Mariana
Ingeniería Mecatrónica
San Juan de Pasto

Área de trabajo: Trabajo de Grado | | Código: 012

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

Descripción: Soporte Panel Solar 1 | Rev: | HOJA 1 de 1

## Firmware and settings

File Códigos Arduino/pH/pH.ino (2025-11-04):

#include <Arduino.h>
#include <Wire.h>
#include <U8g2lib.h>

#include <OneWire.h>
#include <DallasTemperature.h>

#include <Adafruit_ADS1X15.h>
#include "DFRobot_ESP_PH_WITH_ADC.h"

#include <Preferences.h>

#include <WiFi.h>
#include <esp_now.h>
#include <esp_wifi.h>
#include <esp_idf_version.h>

// ----------------- Ajustes hardware -----------------
#define I2C_SDA 8
#define I2C_SCL 9
#define ONEWIRE_PIN 5
#define OLED_SDA I2C_SDA
#define OLED_SCL I2C_SCL

#define BTN_ENTER_CAL 7
#define BTN_EXIT_CAL 10
#define BTN_SAVE_CAL 20

#define ADS_CHANNEL 0  // A0 corresponde al canal 0

const unsigned long SEND_INTERVAL_MS = 140000UL;
const unsigned long ADS_READ_MS = 1000UL;
const unsigned long DEBOUNCE_MS = 200UL;  // antirrebote botones

uint8_t peerMAC[6] = { 0xC8, 0x2E, 0x18, 0xAD, 0x53, 0xCC };  // Receptor

U8G2_SSD1306_128X64_NONAME_F_HW_I2C u8g2(U8G2_R0, U8X8_PIN_NONE);
OneWire oneWire(ONEWIRE_PIN);
DallasTemperature ds(&oneWire);

Adafruit_ADS1115 ads;
DFRobot_ESP_PH_WITH_ADC phSensor;

Preferences prefs;

float calib_a = 3.5f;
float calib_b = 0.0f;
bool calib_valid = false;

bool cal_waiting_for_second = false;
float cal_v_point1 = NAN;
float cal_ph_point1 = NAN;

unsigned long lastAdsRead = 0;
float lastVoltage = NAN;
float lastPH = NAN;
float lastTemp = NAN;

uint32_t seqSend = 1;
bool inCalibration = false;

bool espNowOk = false;

// Estado de último envío ESP-NOW
volatile esp_now_send_status_t lastSendStatus = ESP_NOW_SEND_FAIL;

// Estructura mensaje
#pragma pack(push, 1)
struct MsgPH {
  uint8_t kind;
  float ph;
  float tempC;
  uint32_t seq;
};
#pragma pack(pop)

// ---------- Forward decls ----------
void drawMainScreen(bool ph_ok, bool temp_ok);
void drawCalibrationScreen(const char* line1, const char* line2, const char* line3);
float readADSVoltage();
float applyCalibrationAndTempCompensation(float volt, float tempC);
bool computeTwoPointCalibration(float v1, float p1, float v2, float p2, float& out_a, float& out_b);
void saveCalibrationToPrefs();
void loadCalibrationFromPrefs();

// ----------------- esp-now send callback -----------------
#if ESP_IDF_VERSION_MAJOR >= 5
void onSendCallback(const wifi_tx_info_t* info, esp_now_send_status_t status) {
  lastSendStatus = status;  // guardar estado
  if (status == ESP_NOW_SEND_SUCCESS) Serial.println("ESP-NOW send: SUCCESS");
  else Serial.printf("ESP-NOW send: FAIL status=%d\n", (int)status);
}
#else
void onSendCallback(const uint8_t* mac_addr, esp_now_send_status_t status) {
  lastSendStatus = status;  // guardar estado
  if (status == ESP_NOW_SEND_SUCCESS) Serial.println("ESP-NOW send: SUCCESS");
  else Serial.printf("ESP-NOW send: FAIL status=%d\n", (int)status);
}
#endif

// ----------------- Helpers -----------------
void saveCalibrationToPrefs() {
  prefs.putFloat("cal_a", calib_a);
  prefs.putFloat("cal_b", calib_b);
  prefs.putBool("cal_ok", true);
  Serial.printf("Saved calibration a=%.6f b=%.6f\n", calib_a, calib_b);
}
void loadCalibrationFromPrefs() {
  if (prefs.getBool("cal_ok", false)) {
    calib_a = prefs.getFloat("cal_a", 3.5f);
    calib_b = prefs.getFloat("cal_b", 0.0f);
    calib_valid = true;
    Serial.printf("Loaded calibration a=%.6f b=%.6f\n", calib_a, calib_b);
  } else {
    calib_valid = false;
    Serial.println("No calibration saved - using defaults");
  }
}

float readADSVoltage() {
  int16_t raw = ads.readADC_SingleEnded(ADS_CHANNEL);
  float lsb_mV = 0.125F;  // mV por bit para GAIN_ONE
  float mv = raw * lsb_mV;
  return mv / 1000.0F;  // resultado en voltios
}

float applyCalibrationAndTempCompensation(float volt, float tempC) {
  float ph_lin = calib_a * volt + calib_b;
  float ph_corr = ph_lin + (25.0f - tempC) * 0.03f;
  return ph_corr;
}

// ----- Leer y promediar varias muestras del ADS1115 (devuelve V) -----
float readADSVoltageAverage(int samples = 8, unsigned int delayMsBetween = 5) {
  long acc = 0;
  int valid = 0;
  for (int i = 0; i < samples; ++i) {
    int16_t raw = ads.readADC_SingleEnded(ADS_CHANNEL);
    acc += raw;
    valid++;
    delay(delayMsBetween);
  }
  if (valid == 0) return NAN;
  float avgRaw = (float)acc / (float)valid;
  float lsb_mV = 0.125F;  // mV por bit para GAIN_ONE
  float mv = avgRaw * lsb_mV;
  return mv / 1000.0F;  // voltios
}

// ----- Leer temperatura actual (retorna 25.0 si desconectado) -----
float readTempC() {
  ds.requestTemperatures();
  float t = ds.getTempCByIndex(0);
  if (t == DEVICE_DISCONNECTED_C || isnan(t)) return 25.0f;
  return t;
}


bool computeTwoPointCalibration(float v1, float p1, float v2, float p2, float& out_a, float& out_b) {
  if (isnan(v1) || isnan(v2) || fabsf(v1 - v2) < 1e-9) return false;
  out_a = (p2 - p1) / (v2 - v1);
  out_b = p1 - out_a * v1;
  return true;
}

// ----------------- OLED Screens -----------------
void drawMainScreen(bool ph_ok, bool temp_ok) {
  u8g2.clearBuffer();
  u8g2.setFont(u8g2_font_6x12_tf);
  char buf[64];

  // 1. Estado ESP-NOW (según callback)
  const char* statusMsg;
  if (lastSendStatus == ESP_NOW_SEND_SUCCESS) statusMsg = "ok";
  else statusMsg = "error";
  u8g2.drawStr(2, 12, "ESP-NOW:");
  u8g2.drawStr(70, 12, statusMsg);

  // 2. pH
  if (ph_ok && !isnan(lastPH)) snprintf(buf, sizeof(buf), "pH: %.3f", lastPH);
  else snprintf(buf, sizeof(buf), "pH: --.- (nan)");
  u8g2.drawStr(2, 28, buf);

  // 3. Temperatura
  if (temp_ok && !isnan(lastTemp)) snprintf(buf, sizeof(buf), "T: %.2f C", lastTemp);
  else snprintf(buf, sizeof(buf), "T: 25.00 C (def)");
  u8g2.drawStr(2, 44, buf);

  // 4. Ayuda botones
  u8g2.setFont(u8g2_font_5x8_tf);
  u8g2.drawStr(2, 62, "BTN: ENTER / SAVE / EXIT");

  u8g2.sendBuffer();
}

void drawCalibrationScreen(const char* line1, const char* line2, const char* line3) {
  u8g2.clearBuffer();
  u8g2.setFont(u8g2_font_6x10_tf);
  u8g2.drawStr(2, 12, "=== CALIBRACION ===");
  u8g2.drawStr(2, 28, line1);
  u8g2.drawStr(2, 44, line2);
  u8g2.drawStr(2, 60, line3);
  u8g2.sendBuffer();
}

// ----------------- Setup -----------------
void setup() {
  Serial.begin(115200);
  delay(50);

  Wire.begin(I2C_SDA, I2C_SCL);
  u8g2.begin();

  pinMode(BTN_ENTER_CAL, INPUT_PULLUP);
  pinMode(BTN_EXIT_CAL, INPUT_PULLUP);
  pinMode(BTN_SAVE_CAL, INPUT_PULLUP);

  ds.begin();

  ads.setGain(GAIN_ONE);
  if (!ads.begin()) Serial.println("Failed to initialize ADS1115");
  else Serial.println("ADS1115 OK");

  phSensor.begin();

  prefs.begin("ph_cal", false);
  loadCalibrationFromPrefs();

  WiFi.mode(WIFI_STA);
  esp_wifi_set_channel(6, WIFI_SECOND_CHAN_NONE);

  if (esp_now_init() != ESP_OK) {
    Serial.println("Error initializing ESP-NOW");
    espNowOk = false;
  } else {
    Serial.println("ESP-NOW init OK");
    espNowOk = true;
    esp_now_register_send_cb(onSendCallback);

    esp_now_peer_info_t peerInfo;
    memset(&peerInfo, 0, sizeof(peerInfo));
    memcpy(peerInfo.peer_addr, peerMAC, 6);
    peerInfo.channel = 6;
    peerInfo.encrypt = false;

    if (esp_now_add_peer(&peerInfo) != ESP_OK) Serial.println("Failed to add peer");
    else Serial.println("Peer added");
  }

  drawMainScreen(false, false);
  delay(10000);
}

// ----------------- Loop -----------------
void loop() {
  static unsigned long lastSend = 0;
  static unsigned long lastAdsReadLocal = 0;
  static unsigned long lastBtnEnter = 0, lastBtnSave = 0, lastBtnExit = 0;

  unsigned long now = millis();

  // ===== Lectura sensores =====
  if (now - lastAdsReadLocal >= ADS_READ_MS) {
    lastAdsReadLocal = now;

    ds.requestTemperatures();
    float t = ds.getTempCByIndex(0);
    lastTemp = (t == DEVICE_DISCONNECTED_C) ? 25.0f : t;

    float volt = readADSVoltage();
    lastVoltage = volt;

    bool ph_ok = false;
    if (!isnan(volt)) {
      if (calib_valid) {
        lastPH = applyCalibrationAndTempCompensation(volt, lastTemp);
        ph_ok = true;
      } else {
        float volt_mV = volt * 1000.0f;
        float fromLib = phSensor.readPH(volt_mV, lastTemp);
        if (!isnan(fromLib) && isfinite(fromLib)) {
          lastPH = fromLib;
          ph_ok = true;
        }
      }
    }

    if (inCalibration) {
      if (!cal_waiting_for_second)
        drawCalibrationScreen("Probe in pH 7.0", "Press SAVE to capture", "");
      else
        drawCalibrationScreen("Probe in pH 4.0", "Press SAVE to capture", "Then compute & save");
    } else {
      drawMainScreen(ph_ok, !isnan(lastTemp));
    }
  }

  // ===== Botones =====
  if (digitalRead(BTN_ENTER_CAL) == LOW && now - lastBtnEnter > DEBOUNCE_MS) {
    lastBtnEnter = now;
    if (!inCalibration) {
      inCalibration = true;
      cal_waiting_for_second = false;
      // Forzar lectura inicial para mostrar dato estable en pantalla
      lastVoltage = readADSVoltageAverage(12, 6);
      lastTemp = readTempC();
      drawCalibrationScreen("Probe in pH 7.0", "Press SAVE to capture", "");
      Serial.println("Calibration started: put probe in pH 7.0");
    }
  }


  if (digitalRead(BTN_SAVE_CAL) == LOW && now - lastBtnSave > DEBOUNCE_MS) {
    lastBtnSave = now;
    if (inCalibration) {
      // Leer promediado en el momento de pulsar SAVE
      float currentVolt = readADSVoltageAverage(12, 6);  // 12 muestras, 6ms entre ellas
      float currentTemp = readTempC();

      if (isnan(currentVolt)) {
        Serial.println("SAVE: Voltaje NAN, intenta de nuevo");
        drawCalibrationScreen("Lectura invalida", "Voltaje NAN, reintenta", "");
        delay(700);
        return;
      }

      if (!cal_waiting_for_second) {
        // Captura punto 1 (pH 7)
        cal_v_point1 = currentVolt;
        cal_ph_point1 = 7.0f;
        cal_waiting_for_second = true;
        Serial.printf("Captured point1: V=%.6f V  T=%.2f C  pH=7.0\n", cal_v_point1, currentTemp);
        char l1[32];
        snprintf(l1, sizeof(l1), "PUNTO1 V: %.4f V", cal_v_point1);
        char l2[32];
        snprintf(l2, sizeof(l2), "Temp: %.2f C", currentTemp);
        drawCalibrationScreen(l1, l2, "Ahora pH 4.0 y SAVE");
      } else {
        // Captura punto 2 (pH 4) y calcular
        float v2 = currentVolt;
        float p2 = 4.0f;
        Serial.printf("Captured point2: V=%.6f V  T=%.2f C  pH=4.0\n", v2, currentTemp);

        // Comprobaciones: no NAN y voltajes distintos
        if (isnan(cal_v_point1) || isnan(v2)) {
          Serial.println("Calibration failed: NAN values");
          drawCalibrationScreen("Error:", "Lectura NAN", "Abortando");
          inCalibration = false;
          cal_waiting_for_second = false;
          delay(800);
        } else if (fabsf(cal_v_point1 - v2) < 1e-4f) {
          // Si las lecturas son prácticamente iguales, fallamos - muy ruidoso o sonda mal
          Serial.println("Calibration failed: voltages too similar");
          drawCalibrationScreen("Error:", "Voltajes muy similares", "Reinicia y reintenta");
          inCalibration = false;
          cal_waiting_for_second = false;
          delay(1200);
        } else {
          float a, b;
          if (computeTwoPointCalibration(cal_v_point1, cal_ph_point1, v2, p2, a, b)) {
            calib_a = a;
            calib_b = b;
            calib_valid = true;
            saveCalibrationToPrefs();
            Serial.printf("Calibration done: a=%.6f b=%.6f\n", calib_a, calib_b);

            char l1[32];
            snprintf(l1, sizeof(l1), "CAL OK a: %.4f", calib_a);
            char l2[32];
            snprintf(l2, sizeof(l2), "b: %.4f", calib_b);
            drawCalibrationScreen("Calibracion exitosa", l1, l2);
            delay(1200);
          } else {
            Serial.println("Calibration computeTwoPointCalibration returned false");
            drawCalibrationScreen("Calculo fallido", "verifica lecturas", "");
            delay(1200);
          }
          inCalibration = false;
          cal_waiting_for_second = false;
        }
      }
    }
  }


  if (digitalRead(BTN_EXIT_CAL) == LOW && now - lastBtnExit > DEBOUNCE_MS) {
    lastBtnExit = now;
    if (inCalibration) {
      inCalibration = false;
      Serial.println("Calibration aborted");
    }
  }

  // ===== Envío ESP-NOW =====
  if (!inCalibration && (millis() - lastSend >= SEND_INTERVAL_MS)) {
    lastSend = millis();
    MsgPH msg;
    msg.kind = 1;
    msg.ph = lastPH;
    msg.tempC = lastTemp;
    msg.seq = seqSend++;

    esp_err_t res = esp_now_send(peerMAC, (uint8_t*)&msg, sizeof(msg));
    if (res != ESP_OK) Serial.printf("esp_now_send failed: %d\n", (int)res);
    else Serial.printf("Sent ph=%.3f T=%.2f seq=%u\n", msg.ph, msg.tempC, msg.seq);
  }

  delay(10);
}

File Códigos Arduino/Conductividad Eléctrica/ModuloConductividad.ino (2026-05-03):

#include <Arduino.h>
#include <Wire.h>
#include <U8g2lib.h>

#include <OneWire.h>
#include <DallasTemperature.h>

#include <Adafruit_ADS1X15.h>
#include "DFRobot_ESP_EC.h"
#include <Preferences.h>

#include <WiFi.h>
#include <esp_now.h>
#include <esp_wifi.h>

// ----------------- Ajustes hardware -----------------
#define I2C_SDA 8
#define I2C_SCL 9

#define ONEWIRE_PIN 5
#define OLED_SDA I2C_SDA
#define OLED_SCL I2C_SCL

// Botones (INPUT_PULLUP)
#define BTN_ENTER_CAL 7
#define BTN_SAVE_CAL 10
#define BTN_EXIT_CAL 20

#define ADS_CHANNEL 0

// Timings
const unsigned long DEBOUNCE_MS = 200UL;

// Peer MAC (receptor) -- ajusta si cambia
uint8_t peerMAC[6] = { 0xC8, 0x2E, 0x18, 0xAD, 0x53, 0xCC };

// Mensajes kind IDs
const uint8_t KIND_EC = 2;  // EC + temp

// ---------- Periféricos ----------
U8G2_SSD1306_128X64_NONAME_F_HW_I2C u8g2(U8G2_R0, U8X8_PIN_NONE);
OneWire oneWire(ONEWIRE_PIN);
DallasTemperature ds(&oneWire);

Adafruit_ADS1115 ads;
DFRobot_ESP_EC ecSensor;

Preferences prefs;

// Estado / variables
volatile esp_now_send_status_t lastSendStatus = ESP_NOW_SEND_FAIL;
bool peerAdded = false;
bool useBroadcastFallback = false;

float lastTemp = NAN;
bool haveECreading = false;
// lastEC en µS/cm
float lastEC_mS = NAN;
float lastEC_uS = NAN;
float lastVoltage = NAN;

uint32_t seqSend = 1;

// Calibration state
bool inCalibration = false;
bool cal_captured = false;
float cal_voltage_point = NAN;
// 1.413 mS/cm == 1413 µS/cm
float cal_ec_value = 1.413f;
bool cal_saved = false;

// Preferences keys
const char* PREF_NAMESPACE = "ec_cal";
const char* PREF_CAL_OK = "cal_ok";
const char* PREF_LAST_CAL_V = "cal_v";
const char* PREF_LAST_CAL_EC = "cal_ec";

// Mensaje (emisor -> receptor)
#pragma pack(push, 1)
struct MsgEC {
  uint8_t kind;  // 2 = EC+temp
  float ec;      // µS/cm (or -1 if none)
  float tempC;
  uint32_t seq;
};
#pragma pack(pop)

// ---------- Detección unidad librería EC ----------
bool ecLibExpects_mV = false;   // si true, pasar mV (volts*1000) a readEC/calibration
bool ecUnitDetected = false;    // detector ejecutado

// ---------- Forward decls ----------
void drawMainScreen();
void drawCalScreen(const char* l1, const char* l2, const char* l3);
float readADSVoltage_mv_like_example();
float readADSVoltageAvg(int samples = 8, unsigned long delayMs = 20);
void loadCalibrationPrefs();
void saveCalibrationPrefs();
bool ensurePeerAdded();
bool sendWithRetries(const uint8_t* dest, const uint8_t* data, size_t len);
void sendECMessage(float ec, float temp, uint8_t kind);
bool detectEcLibUnit(float volts, float temp);

// ---------- ESP-NOW callback ----------
#if ESP_IDF_VERSION_MAJOR >= 5
void onSendCallback(const wifi_tx_info_t* info, esp_now_send_status_t status) {
  lastSendStatus = status;
  if (status == ESP_NOW_SEND_SUCCESS) Serial.println("ESP-NOW send callback: SUCCESS");
  else Serial.printf("ESP-NOW send callback: FAIL status=%d\n", (int)status);
}
#else
void onSendCallback(const uint8_t* mac_addr, esp_now_send_status_t status) {
  lastSendStatus = status;
  if (status == ESP_NOW_SEND_SUCCESS) Serial.println("ESP-NOW send callback: SUCCESS");
  else Serial.printf("ESP-NOW send callback: FAIL status=%d\n", (int)status);
}
#endif

// ---------- Helpers ----------
float readADSVoltage_mv_like_example() {
  int16_t raw = ads.readADC_SingleEnded(ADS_CHANNEL);
  float mv = raw * 0.125f;  // LSB mV for GAIN_ONE
  return mv / 1000.0f;      // devuelve V
}

// PROMEDIO ADS (devuelve V)
float readADSVoltageAvg(int samples, unsigned long delayMs) {
  double sum = 0.0;
  for (int i = 0; i < samples; ++i) {
    int16_t raw = ads.readADC_SingleEnded(ADS_CHANNEL);
    float mv = raw * 0.125f;  // LSB mV for GAIN_ONE
    sum += (mv / 1000.0f);    // pasar a V
    delay(delayMs);
  }
  return (float)(sum / samples);
}

// Detección heurística de si la librería espera V o mV.
// Devuelve true si parece esperar mV.
bool detectEcLibUnit(float volts, float temp) {
  // Llamada normal (V)
  float ec_mS_normal = ecSensor.readEC(volts, temp);
  // Llamada con mV
  float ec_mS_mV = ecSensor.readEC(volts * 1000.0f, temp);

  Serial.printf("detectEcLibUnit: normal-> %.6f mS/cm, with mV-> %.6f mS/cm\n", ec_mS_normal, ec_mS_mV);

  bool normal_ok = isfinite(ec_mS_normal) && (ec_mS_normal > 0.05f);
  bool mv_ok     = isfinite(ec_mS_mV)     && (ec_mS_mV > 0.05f);

  if (!normal_ok && mv_ok) {
    Serial.println("detectEcLibUnit: decided -> library expects mV");
    return true;
  } else if (normal_ok && !mv_ok) {
    Serial.println("detectEcLibUnit: decided -> library expects V");
    return false;
  } else {
    // Ambiguo: preferir V (comportamiento por defecto) y avisar
    Serial.println("detectEcLibUnit: ambiguous result; defaulting to V (please check Serial outputs)");
    return false;
  }
}

void loadCalibrationPrefs() {
  prefs.begin(PREF_NAMESPACE, true);
  bool ok = prefs.getBool(PREF_CAL_OK, false);
  if (ok) {
    cal_captured = true;
    cal_voltage_point = prefs.getFloat(PREF_LAST_CAL_V, NAN);
    cal_ec_value = prefs.getFloat(PREF_LAST_CAL_EC, 1.413f);
    cal_saved = true;
    Serial.printf("Loaded calibration prefs: V=%.6f V, EC=%.4f mS/cm (%.0f µS/cm)\n",
                  cal_voltage_point, cal_ec_value, cal_ec_value * 1000.0f);
  } else {
    cal_saved = false;
    cal_captured = false;
    Serial.println("No calibration in prefs");
  }
  prefs.end();
}

void saveCalibrationPrefs() {
  prefs.begin(PREF_NAMESPACE, false);
  prefs.putBool(PREF_CAL_OK, true);
  prefs.putFloat(PREF_LAST_CAL_V, cal_voltage_point);
  prefs.putFloat(PREF_LAST_CAL_EC, cal_ec_value);
  prefs.end();
  Serial.printf("Saved calibration prefs: V=%.6f V, EC=%.4f mS/cm (%.0f µS/cm)\n",
                cal_voltage_point, cal_ec_value, cal_ec_value * 1000.0f);
}

// Ensures peer added; if fails, sets useBroadcastFallback true
bool ensurePeerAdded() {
  if (peerAdded) return true;

  esp_now_peer_info_t peer;
  memset(&peer, 0, sizeof(peer));
  memcpy(peer.peer_addr, peerMAC, 6);
  peer.channel = 0;
  peer.encrypt = false;

  esp_err_t rc = esp_now_add_peer(&peer);
  if (rc == ESP_OK) {
    Serial.println("ensurePeerAdded: peer agregado OK");
    peerAdded = true;
    useBroadcastFallback = false;
    return true;
  } else {
    Serial.printf("ensurePeerAdded: fallo esp_now_add_peer 0x%08X -> fallback broadcast\n", (unsigned)rc);
    peerAdded = false;
    useBroadcastFallback = true;
    return false;
  }
}
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

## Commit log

2025-11-04 Agrego módelos 3D y planos
    [Agarradera Lateral.idw, Agarradera Superior.idw, Agarradera principal.idw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]
2026-05-03 Codigos arduino act
2026-05-03 Actualización Planos
    [001 Plano 1 - Módulo Principal (Caja).idw, 002 Plano 2 - Módulo Principal (Tapa).idw, 003 Plano 3 - Módulo de Conductividad (Caja).idw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]
2026-05-03 Planos Finales
    [001 Plano 1 - Módulo Principal (Caja).idw, 002 Plano 2 - Módulo Principal (Tapa).idw, 003 Plano 3 - Módulo de Conductividad (Caja).idw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]
